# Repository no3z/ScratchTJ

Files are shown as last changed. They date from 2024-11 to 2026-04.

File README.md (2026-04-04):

# ScratchTJ MK2 -- DIY Digital Scratch Turntable

A fully open-source portable scratch instrument built around a Raspberry Pi, Arduino Nano, and the [xwax](http://www.xwax.co.uk/) digital vinyl emulation engine.

This project is based on the work by **[the_rasteri](https://github.com/rasteri)** and the [SC1000](https://github.com/rasteri/SC1000) open-source portable turntable. The software is a fork of the SC1000 codebase, and the hardware design draws heavily from that project. Without rasteri's original work, ScratchTJ would not exist.

> **Project status:** this repository tracks **MK2**.
> The previous generation is preserved in Git tag **`mk1`**.

**[Full Build Guide](docs/BUILD_GUIDE.md)** -- step-by-step wiring, assembly, and component documentation.

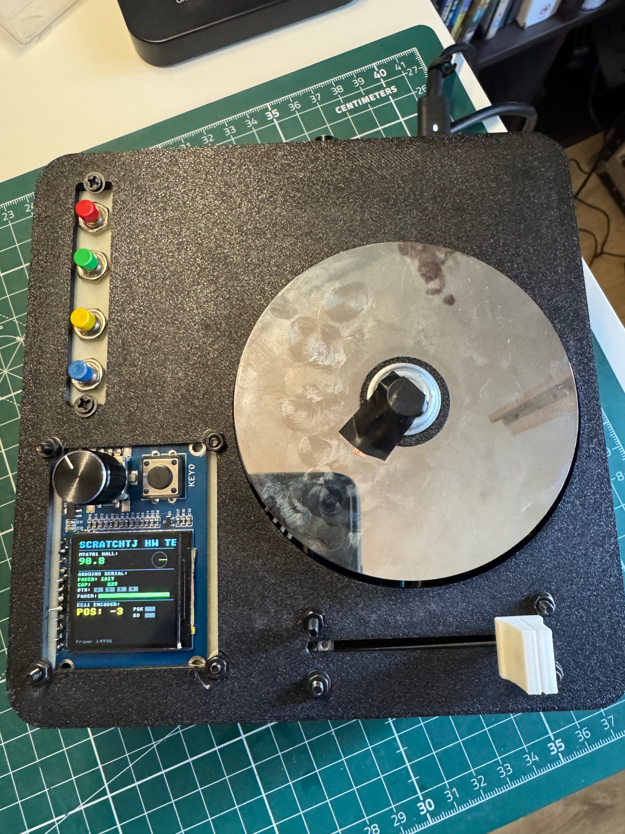
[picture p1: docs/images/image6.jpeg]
MK2 top view -- platter, TFT display, buttons, and fader


▶ *Click to play video:*

Scratch demo (https://youtu.be/LH9r2fsUk-c?si=Gcfz0AI6pA22WaxF)

## Features

- Two independent decks: beats + scratch sample, mixed through a DJ fader
- MT6701 magnetic angle sensor for high-precision platter tracking (MK2 upgrade from 600 PPR optical)
- ST7789 240x240 TFT display with rotary encoder menu navigation
- Touch-sensitive HDD platter with capacitive sensing
- Four cue buttons via Arduino (A0--A3) with short-press jump and long-press set
- Two function modes for cue buttons: **CUE** (jump/set cue points) and **SETTINGS** (platter-based parameter control)
- SETTINGS mode: hold button + rotate platter to adjust pitch, platterspeed, volume (gain), or toggle start/stop
- Active deck switching via rotary long press -- platter, cue buttons, and display follow selected deck
- Live input recording from AudioInjector capture
- Save/load configuration via Config menu
- Binary serial protocol at 500 kbaud between Arduino and Pi
- All key parameters tunable in real time from the menu or SETTINGS function buttons

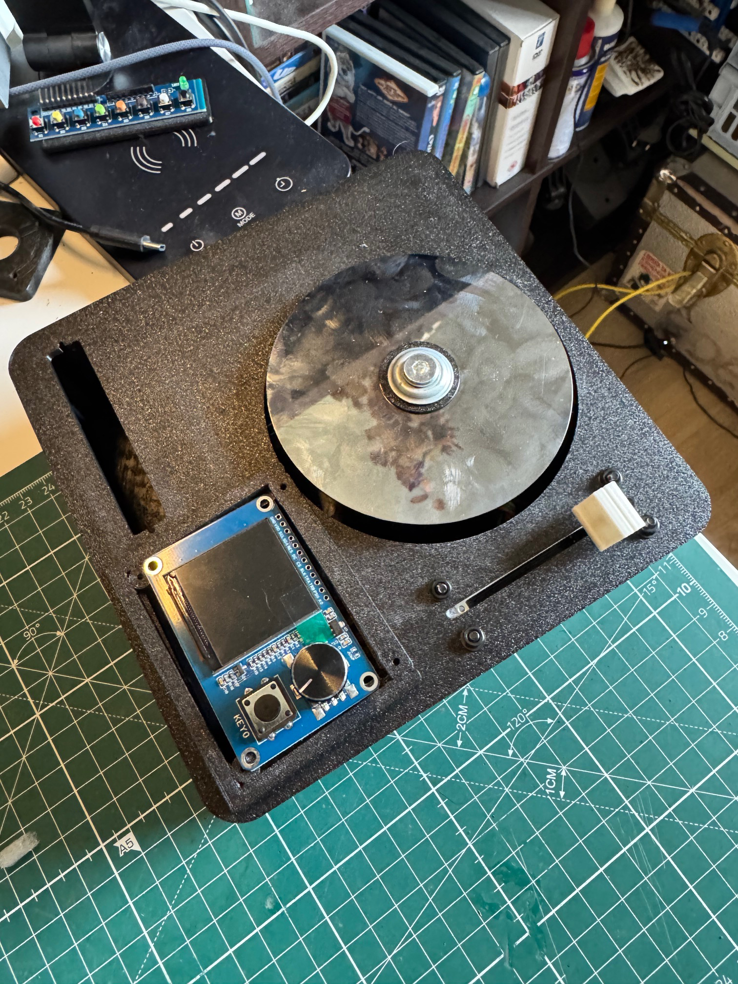
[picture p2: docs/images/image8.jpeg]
MK2 alternate angle -- TFT and platter closeup


▶ *Click to play video:*

Randomize function scratch (https://youtu.be/6zyM5B6j0_E?si=wSV1pAbMLMZF-k79)

## Architecture

```
+--------------+   Serial 500kbaud   +--------------+   I2S Audio   +-----------------+
| Arduino Nano | ------------------- | Raspberry Pi | ------------ | AudioInjector   |
|              |   7-byte binary pkt |              |              | Sound Card      |
| - Fader      |   (sync+data+XOR)   | - xwax       |              +-----------------+
| - Cap sensor |                     | - TFT menu   |
| - 4 cue btns |                     |              |
+--------------+                     | - MT6701 I2C |
                                     | - Recording  |
                                     +--------------+
```

The Arduino handles the DJ crossfader, capacitive touch sensor, and 4 cue buttons, sending data as 7-byte binary packets with XOR checksum at ~500 Hz. The Raspberry Pi reads the MT6701 magnetic encoder via I2C, runs the audio engine, TFT menu system, and live recording.

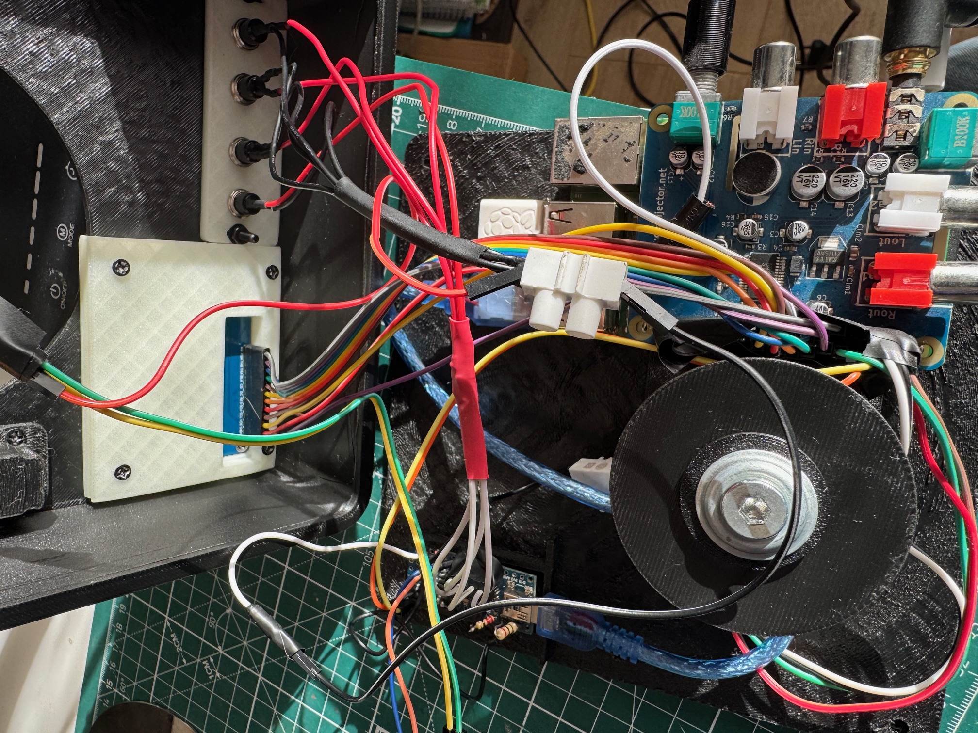
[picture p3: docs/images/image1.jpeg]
MK2 internals -- wiring, platter mount, and AudioInjector sound card


## Bill of Materials

- **Raspberry Pi** (2/3/4)
- **AudioInjector Sound Card** (I2S audio HAT)
- **Arduino Nano** (serial at 500 kbaud for fader + cap touch)
- **MT6701 Magnetic Angle Sensor** (I2C, platter position)
- **ST7789 240x240 TFT Display** (SPI, menu UI)
- **Rotary Encoder with Push Button** (menu navigation)
- **60mm DJ Crossfader**
- **HDD Platter** (capacitive touch surface)
- **Cue Buttons** (4x, wired to Arduino A0--A3)
- **Diametric Magnet** (for MT6701 sensing)
- **3D Printed MK2 Enclosure**

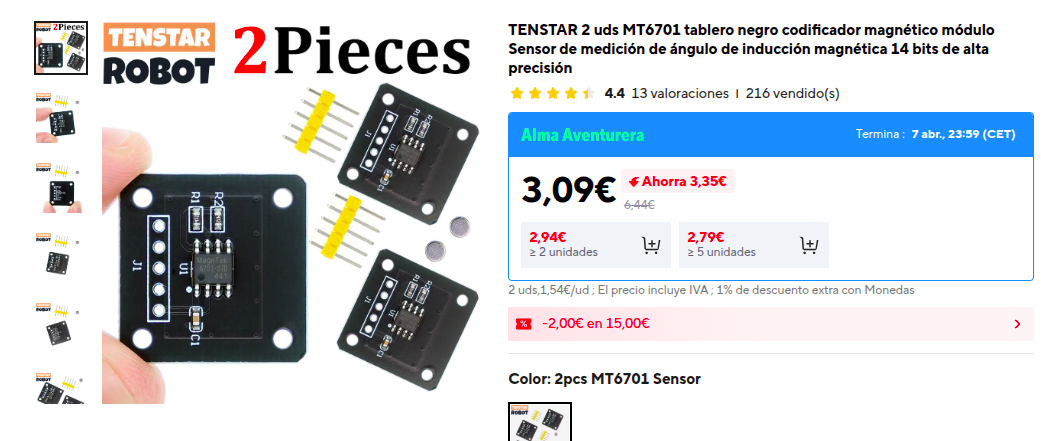
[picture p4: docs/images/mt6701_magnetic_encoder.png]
MT6701 magnetic encoder module

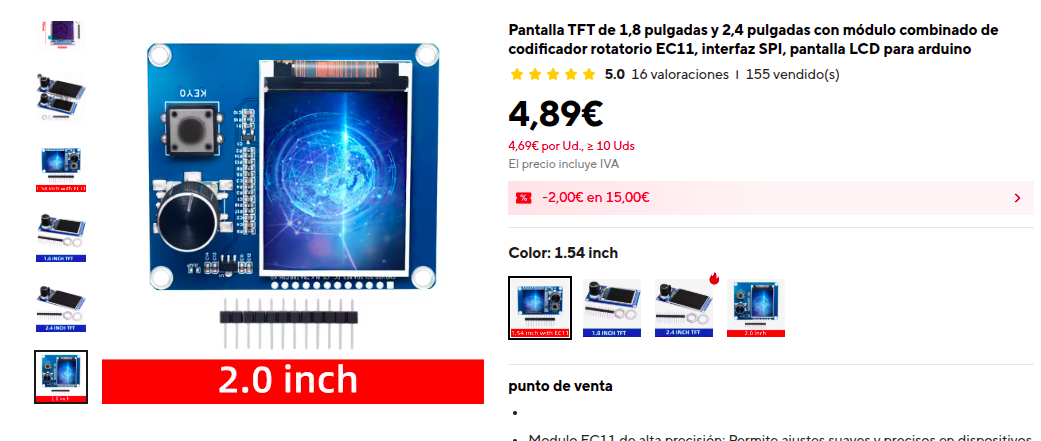
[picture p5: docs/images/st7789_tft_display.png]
ST7789 TFT display module


## Software Overview

Key source files:

| File | Purpose |
|---|---|
| `arduino_nano/arduino_nano.ino` | Arduino firmware: fader, cap sensor, cue buttons, binary serial |
| `software/sc_input.c` | Serial reader, MT6701 I2C encoder, platter-to-audio position mapping |
| `software/player.c` | Audio engine with cubic interpolation, pitch filtering, slipmat simulation |
| `software/xwax.c` | Main application, deck init, shared variable registration |
| `software/recording.c` | Live input recording from ALSA capture devices |
| `software/cues.c` | Cue point system with per-track save/load |
| `software/lcd_menu.c` | TFT display, rotary encoder menu navigation |
| `software/deck_menu.c` | Per-deck menu: file browse, transport, cue screen, recording |
| `software/controller_menu.c` | Config menu: Sound Settings, Global Settings, Info |
| `software/preset_menu.c` | 3-slot preset save/load (compiled, not yet wired into menu) |
| `software/shared_variables.c` | Thread-safe runtime variable system for menu-tunable parameters |

## Menu System

The menu is driven by the EC11 rotary encoder (scroll + push) and the KB0 button (GPIO 17). The home screen shows a live platter visualization for the active deck with info column, fader graph, and cue indicators. A function mode info strip shows the current button assignments.

▶ *Click to play video:*

Menu and buttons demo (https://youtube.com/shorts/j2CSrozANF8?si=jhMayBKkclHSwKNa)

### Full Menu Tree

```
HOME SCREEN
│  Active deck platter visualization (fader arc, ghost/physical needles,
│  touch glow, elapsed time), speed/pitch/motor/slip info column,
│  fader history graph, progress bar, other deck compact strip,
│  function mode info strip, cue flash banner, cue bar overlay
│  Title bar shows [S] indicator when in SETTINGS mode
│  Long press rotary = switch active deck (DECK 1 ↔ DECK 2)
│  KB0 or encoder turn → Main Menu
│
├── Dk2 [▶/■] filename 0:00  .. Deck 2
│   ├── Load File
│   │   ├── Start/Stop
│   │   ├── Next File
│   │   ├── Previous File
│   │   ├── Random File
│   │   ├── Next Folder
│   │   ├── Previous Folder
│   │   └── Record ............ enter recording workflow
│   │   (KB0 enters folder/file browser for the selected action)
│   ├── Start/Stop ............. toggle playback
│   ├── Settings
│   │   ├── Jog Pitch Mode ..... toggle pitch bend via platter
│   │   ├── Toggle Jog Reverse . reverse platter direction
│   │   └── Platter Speed ...... adjust encoder-to-audio ratio
│   └── Info ................... filename, path, position, pitch,
│                                volume, touch state, motor speed, cue points
│
├── Dk1 [▶/■] filename 0:00  .. Deck 1 (same structure as Deck 2)
│
├── Randomize .................. load random tracks on both decks
│
├── Record Dk2 ................. recording workflow
│   ├── Record Setup
│   │   ├── Source .............. AudioInjector hw:1,0 (KB0 cycles)
│   │   └── RECORD ............. KB0 starts capture
│   └── Recording .............. live MM:SS timer, blinking red dot
│                                KB0 = stop (auto-loads into deck)
│
├── Btn: CUE/SETTINGS ......... toggle function mode for cue buttons
│
├── Config
│   ├── Sound Settings ......... all ALSA mixer controls
│   │   └── (per control) ...... volume slider, boolean, or enum
│   ├── Global Settings ........ all registered shared variables
│   │   └── (per variable) ..... value adjust with min/max/step
│   │       (fader variables show live curve graph)
│   ├── Save Config ............ writes to ~/.scratchtj/config.cfg
│   └── Reset Defaults ......... restores all to factory values
│
└── Info
    ├── CPU/Mem ................ live CPU and memory usage
    └── Version ................ "ScratchTJ v2" + build date
```

### Navigation Controls

| Control | Action |
|---|---|
| Encoder rotate | Scroll through menu items / adjust values |
| KB0 button (GPIO 17) | Select / confirm / enter submenu |
| Encoder push (GPIO 27) short press | Back / cancel / return to previous menu |
| Encoder push long press (500ms) | Switch active deck (DECK 1 ↔ DECK 2) |

### Function Modes (CUE / SETTINGS)

Toggle via main menu item "Btn: CUE/SETTINGS". Default is SETTINGS on startup.

**CUE mode** -- cue buttons work as cue points:

| Button | Action |
|---|---|
| Short press | Jump to stored cue point |
| Long press (1s) | Set cue point at current position |

**SETTINGS mode** -- cue buttons become parameter controls:

| Button | Color | Function | Control |
|---|---|---|---|
| Btn 1 | Red | Pitch (note_pitch) | Hold + rotate platter (0.25x -- 4.0x) |
| Btn 2 | Green | Platter Speed | Hold + rotate platter |
| Btn 3 | Yellow | Start/Stop | Press to toggle |
| Btn 4 | Blue | Volume (gain) | Hold + rotate platter (up to x3.60) |

When holding a SETTINGS button and rotating the platter, a live overlay shows the parameter name, value, and gauge bar. Audio position is frozen during adjustment. Config auto-saves when buttons are released.

### Runtime-Tunable Parameters

All adjustable live from Config > Global Settings:

| Parameter | Default | Range | Step | Description |
|---|---|---|---|---|
| Fad Factor | 0.1 | 0.01 - 10 | 0.01 | Fader curve transition point |
| Fad Power | 0.2 | 0.01 - 10 | 0.01 | Fader curve exponent |
| Fad Switch | 1.0 | 0 - 1 | 1.0 | Fader direction (0=normal, 1=reversed) |
| slippiness | 200 | 1 - 3000 | 25 | Slipmat simulation feel |
| target_pitch | 40 | 1 - 240 | 1 | Position tracking gain |
| brakespeed | 3000 | 1 - 10000 | 500 | Stop button deceleration rate |
| platterspeed | 9100 | 1 - 32768 | 256 | Encoder-to-audio position ratio |
| blipthreshold | 400 | 50 - 2048 | 50 | Encoder glitch rejection threshold |
| pitch_filter | 0.1 | 0.01 - 1.0 | 0.01 | Pitch low-pass filter (0=smooth, 1=instant) |
| fader_sharp | 1.0 | 0 - 1.0 | 0.05 | Fader sharpness |
| fhist_secs | 2.0 | 0.1 - 120 | 0.1 | Fader history graph time window (seconds) |

### Serial Protocol

```
Byte:  [0]     [1]     [2]     [3]     [4]     [5]       [6]
       SYNC    fHi     fLo     capHi   capLo   buttons   XOR
       0xAA    ──fader──       ──cap touch──    4-bit     checksum
               (10-bit)        (16-bit)         bitfield  (bytes 1-5)
```

In MK2, the Arduino no longer sends encoder angle data -- the Pi reads the MT6701 directly over I2C. The packet is 7 bytes: sync, fader (2), cap touch (2), cue buttons (1), checksum (1).

Handshake: Pi sends `0x53` ('S'), Arduino replies `'T'`. Watchdog detects 2-second timeouts with DTR hard-reset after 3 consecutive failures.

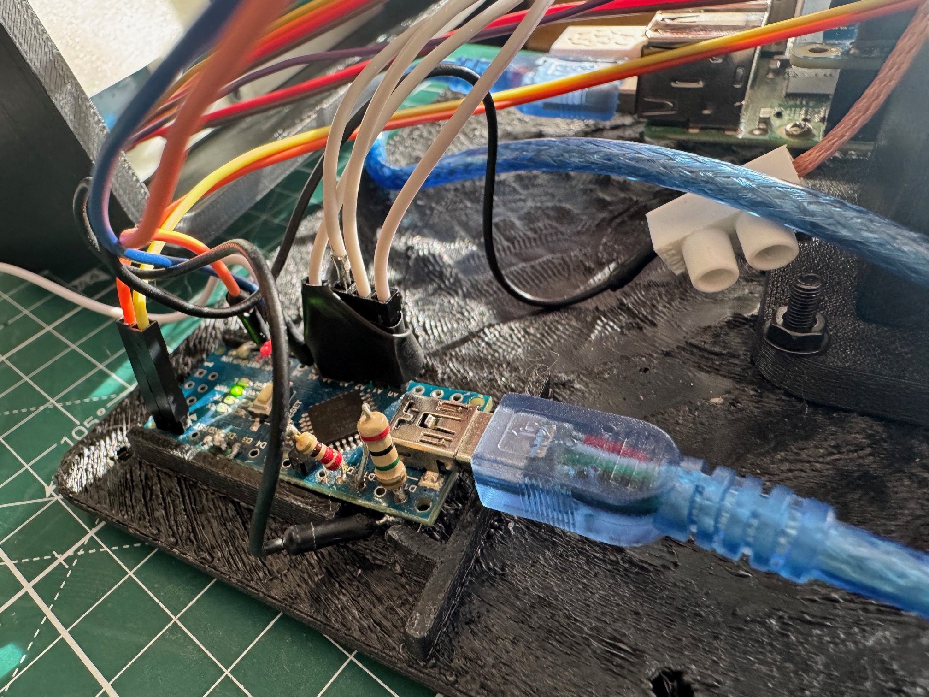
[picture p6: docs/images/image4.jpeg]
Arduino Nano in its 3D printed cradle -- the 1.2kΩ resistor and the wire going to the platter spring contact are both soldered to the same D12 sense pin


## Building

### Prerequisites (on the Raspberry Pi)

- GCC, make
- SDL2 development libraries
- ALSA development libraries
- wiringPi

### Compile and Run

```bash
cd ~/ScratchTJ/software
make -j4
sudo LC_ALL=en_GB.utf8 nice -n -19 ./xwax
```

If locale is not set as above, xwax may fail to start correctly.

### Flash the Arduino

Open `arduino_nano/arduino_nano.ino` in the Arduino IDE. Install the `CapacitiveSensor` library, select Arduino Nano, and upload. Both the Arduino firmware and the Pi software must be updated together since they share the binary serial protocol.

Audio samples go in `~/samples/` (scratch deck) and `~/beats/` (beat deck). The paths are configured in `xwax.c`.

▶ *Click to play video:*

Little scratch demo (https://youtube.com/shorts/L9gylG18938?si=5t2caiyyweBquCjl)

## Hardware Test Scripts

Hardware test and diagnostic scripts are in the [`hw_test/`](hw_test/) directory.

## Documentation

- **[Build Guide](docs/BUILD_GUIDE.md)** -- Step-by-step wiring and assembly
- **[Installation](docs/INSTALLATION.md)** -- Software installation details
- **[Software Architecture](docs/SOFTWARE.md)** -- Thread model, subsystems
- **[Enclosure Design](docs/enclosure/ENCLOSURE_DESIGN.md)** -- 3D printable parts
- **[Parametric Encoder Mount](docs/enclosure/parametric_encoder_mount.scad)** -- OpenSCAD source for the MT6701 encoder mount (fully parametric)

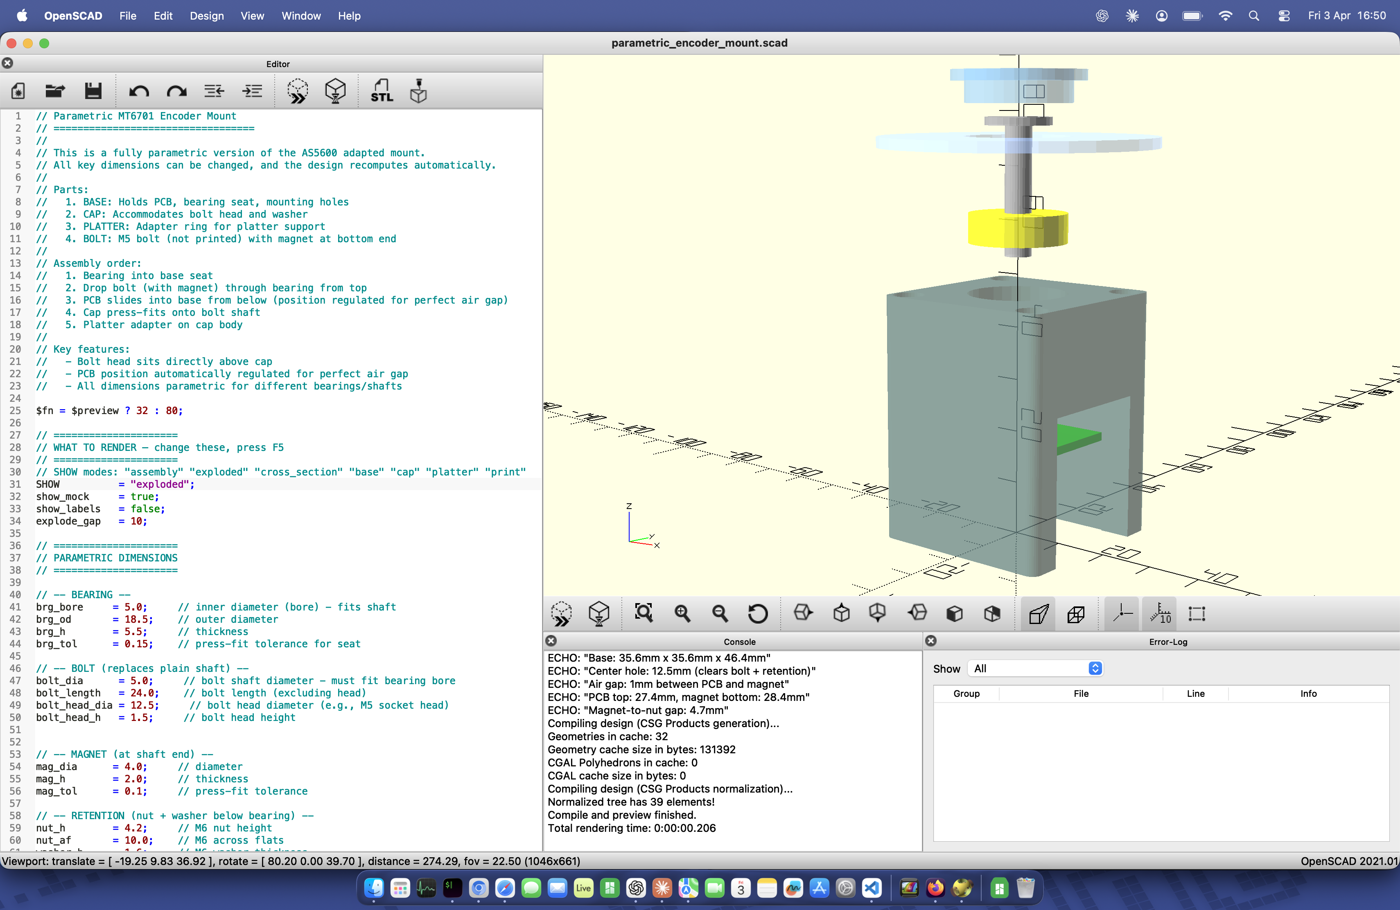
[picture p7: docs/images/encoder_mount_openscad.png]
Encoder mount exploded view in OpenSCAD


## Project History

ScratchTJ started as an adaptation of rasteri's SC1000 to run on a Raspberry Pi with an AudioInjector audio hat, replacing the Olimex A13 and custom PCB with off-the-shelf components (Arduino Nano, standard encoder, DJ fader) and serial communication instead of I2C/SPI.

MK2 replaces the 600 PPR optical encoder with an MT6701 magnetic angle sensor, the 1602A LCD with an ST7789 TFT display, and introduces a redesigned enclosure with better platter support and Hall-sensor alignment.

## License and Attributions

Licensed under GNU GPL v2.

- **[xwax](http://www.xwax.co.uk/)** by Mark Hills -- the digital vinyl emulation engine at the core of this project
- **[SC1000](https://github.com/rasteri/SC1000)** by the_rasteri -- the open-source portable turntable that ScratchTJ is forked from
- **[AudioInjector](http://www.audioinjector.net/)** -- I2S sound card HAT for Raspberry Pi

---

Kiitos paljon ja happy scratching!

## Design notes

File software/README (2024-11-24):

Rebutchered the butchered repository: 
SC1000 Xwax - xwax butchered to work with the SC1000 digital scratch instrument

Added LCD menus, and input interfaces via arduino nano sending data trought serial to rpi

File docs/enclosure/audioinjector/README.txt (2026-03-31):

AudioInjector Case by dj_doughy on Thingiverse: https://www.thingiverse.com/thing:5854768

Summary:
This object was made in Tinkercad. Edit it online https://www.tinkercad.com/things/gVtFypLfkFGThis case was designed for my DIY Eyesy Visual Synth project. More info can be found over at https://blog.djdoughy.com/2022/08/raspberry-pi-4-eyesy-clone-guide.htmlThe case was designed for a RasPi 4, but I believe the openings are big enough to work for a 3B.

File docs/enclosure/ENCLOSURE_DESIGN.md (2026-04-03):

# ScratchTJ v2.0 — Enclosure Design Document

## Overview

Complete redesign of the ScratchTJ DJ controller enclosure, replacing the single-piece Tinkercad box with a modular, parametric OpenSCAD design optimized for the MT6701 magnetic encoder upgrade.

### Key Changes from v1

| Feature | v1 (Current) | v2 (New) |
|---|---|---|
| Enclosure | Single box (Tinkercad) | 2-part: base + top plate |
| Encoder | 600 PPR optical rotary | MT6701 magnetic (14-bit, I2C) |
| Bearing | None (encoder shaft) | 625 bearing (5mm/16mm/5mm) |
| Display | 1602A LCD (I2C 0x27) | SSD1306 0.96" OLED (I2C 0x3C) |
| Touch sensing | Wire through encoder shaft | Slip ring + spring contact |
| Controls | Front panel (LCD sideways) | Top surface (DJ deck style) |
| Design tool | Tinkercad | OpenSCAD (parametric) |

---

## Architecture

### Two-Part Stack

```
        ┌─────────────────────────────────────────────────────┐
        │              TOP PLATE (Part B)                      │
        │  ┌────────┐     ┌─────────────────────────────┐    │
        │  │  OLED  │     │      PLATTER OPENING        │    │
        │  │ (up)   │     │       (always exposed)      │    │
        │  └────────┘     │                             │    │
        │  (ENC)          │         HDD disc            │    │
        │  [A] [B]        │        spins here           │    │
        │                 └─────────────────────────────┘    │
        │  ═══════════ FADER ═══════════                     │
        ├─CLIPS──────────────────────────────────────CLIPS───┤
        │            ELECTRONICS BASE (Part A)                │
        │                                                     │
        │  ┌──────────────────────┐   ┌─────────────────┐   │
        │  │  Raspberry Pi 2/3    │   │  MT6701 sensor  │   │
        │  │  + AudioInjector HAT │   │  on pedestal    │   │
        │  │                      │   │  + 625 bearing  │   │
        │  └──────────────────────┘   │  + rotor hub    │   │
        │  ┌───────────┐              └─────────────────┘   │
        │  │Arduino Nano│                                    │
        │  └───────────┘                                     │
        └─────────────────────────────────────────────────────┘
```

### Top Plate Layout (DJ Deck Style)

All controls face UP for natural DJ interaction:

```
     ┌──────────────────────────────────────────────┐
     │                                               │
     │  ┌────────┐      ┌───────────────────────┐   │
     │  │  OLED  │      │                       │   │
     │  │ 0.96"  │      │                       │   │
     │  └────────┘      │    HDD PLATTER        │   │
     │                   │     Ø95mm             │   │
     │  (🔘 ENC)        │   always exposed      │   │
     │  menu knob        │   touch to scratch    │   │
     │                   │                       │   │
     │  [🔴] [🔵]      │                       │   │
     │  Enter  Back      └───────────────────────┘   │
     │                                               │
     │  ══════════════════════════════════════════   │
     │          60mm CROSSFADER                      │
     │                                               │
     └──────────────────────────────────────────────┘
       FRONT
```

---

## Printable Parts (7 total)

### Part A: Electronics Base — `v2_base.scad`

The main enclosure box. Open top, all electronics mount inside.

- **Dimensions:** ~145mm x 175mm x 60mm (outer) — matches v1 footprint
- Pi standoffs (4x M2.5, 6mm height)
- Arduino Nano friction-fit cradle
- MT6701 sensor pedestal with bearing seat (rises from floor to correct height)
- Fader mounting rails
- 6x clip receivers on inner walls
- Back panel: 4x 3.5mm audio jack holes, micro-USB, HDMI, USB-A cutouts
- Left side: Arduino USB programming access
- Ventilation slots on both sides

### Part B: Top Plate — `v2_top_plate.scad`

DJ deck surface. Clips onto base rim.

- **Thickness:** 4mm (structural)
- Platter opening (Ø100mm) with raised cosmetic surround — fits 95mm HDD platter
- OLED window with bezel (screen faces up)
- OLED PCB pocket (recessed from below)
- EC11 encoder hole with raised ring surround
- 2x button holes with surrounds
- Fader slot (66mm x 4mm)
- 6x clip hooks (snap onto base receivers)
- Cable pass-through slot near platter

### Rotor Hub — `v2_rotor_hub.scad`

The spinning part. Press-fits onto 625 bearing inner race.

- **Dimensions:** Ø26mm body, Ø32mm flange, 12mm tall
- Bottom: 6x2.5mm magnet pocket (press-fit)
- Middle: Slip ring groove (3mm wide, 0.8mm deep for copper tape)
- Wire channel from ring to flange (for platter connection)
- Top: Platter flange with 3x M2 mounting holes
- Radial M2.5 set screw hole
- **Print: 4 walls, 80% infill, 0.16mm layers**

### Fixed Shaft — `v2_shaft.scad`

Stationary shaft through the bearing center.

- Ø4.8mm shaft (clearance fit in 5mm bore)
- Base flange Ø9mm
- M3 through-bolt for securing to pedestal
- Countersink on top for bolt head
- **Print: 100% infill**

### Spring Contact Holder — `v2_spring_holder.scad`

Holds the brass spring strip that presses against the slip ring.

- Slot for 4mm wide spring strip
- Chamfered entry for easy spring insertion
- M2 clamping screw hole (presses spring down)
- Wire hole in bottom (solder connection to Arduino D12)
- Mounting tab with M3 hole (attaches to sensor pedestal)

### Platter Adapter Ring — `v2_platter_adapter.scad`

Optional ring to center the HDD platter on the hub flange.

- Recess for Ø95mm platter
- Center hole clears hub flange
- Weight reduction cutouts

### Legacy reference: `mt6701_mount.scad`

Earlier standalone MT6701 mount design. Superseded by the integrated pedestal in `v2_base.scad`, kept for reference.

---

## Slip Ring System (Capacitive Touch)

### Problem

The v1 design routes a copper wire through the optical encoder shaft to make electrical contact with the HDD platter. With the MT6701 magnetic encoder (contactless), there is no mechanical shaft connection to the platter.

### Solution: Rotating Slip Ring + Fixed Spring Contact

```
    Arduino D12 (sense) ──wire──┐
                                │
                        ╔═══════╧═══════╗
                        ║ SPRING CONTACT ║  (fixed, brass strip)
                        ║   presses on   ║
                        ╚═══════╤═══════╝
                                │ physical contact
                        ╔═══════╧═══════╗
                        ║  COPPER RING   ║  (rotates with hub)
                        ║  in hub groove ║
                        ╚═══════╤═══════╝
                                │ soldered wire
                        ╔═══════╧═══════╗
                        ║  HDD PLATTER   ║  (metal, user touches)
                        ╚═══════════════╝
                                │
                           User's finger
                         (body capacitance)
```

### Circuit

The existing Arduino capacitive sensing circuit is **unchanged**:

```
Arduino D10 ──── 1.2kΩ ──── Arduino D12 ──── wire ──── spring contact
                                                              │
                                                        copper ring
                                                              │
                                                        HDD platter
```

The `CapacitiveSensor` library measures charge time through the 1.2kΩ resistor. When a finger touches the platter, body capacitance increases the charge time, and the reading goes up.

### Materials for Slip Ring

| Item | Specification | Source |
|---|---|---|
| Copper tape | 3mm wide, adhesive back | AliExpress / electronics store |
| Spring strip | Phosphor bronze, 0.1-0.2mm thick, 3mm wide | Cut from shim stock |
| Wire | 26-30 AWG silicone | Standard hookup wire |

### Assembly

1. Wrap copper tape into the rotor hub groove (full ring, overlapping ends)
2. Solder a wire from the copper ring through the hub wire channel to the platter contact point on the flange
3. Bend the brass spring strip — one end curved (contact tip), other end flat (solder pad)
4. Insert spring into holder slot, curved tip pointing toward hub
5. Secure with M2 screw through clamping hole
6. Solder wire from spring flat end to Arduino D12

---

## Wiring Changes (v1 → v2)

### Removed

- 1602A LCD display (I2C address 0x27)
- 600 PPR optical rotary encoder (Arduino D2/D3 interrupts)
- Encoder shaft wire for capacitive touch

### Added

- SSD1306 0.96" OLED (I2C address 0x3C, same SDA/SCL pins)
- MT6701 magnetic encoder (I2C address 0x06, same I2C bus, read directly by Pi)
- Slip ring system (replaces shaft wire, same D10/D12 circuit)

### Modified Arduino Protocol

The Arduino no longer reads the platter encoder. The serial packet shrinks:

| v1 Packet (8 bytes) | v2 Packet (6 bytes) |
|---|---|
| `0xAA` sync | `0xAA` sync |
| Fader high | Fader high |
| Fader low | Fader low |
| ~~Angle high~~ | Cap high |
| ~~Angle low~~ | Cap low |
| Cap high | Checksum (XOR 1-4) |
| Cap low | |
| Checksum | |

The Pi reads the MT6701 angle directly over I2C at address 0x06 (14-bit, register 0x03-0x04).

### I2C Bus Map

| Address | Device | Notes |
|---|---|---|
| 0x06 | MT6701 | 14-bit angle, read by Pi at ~1kHz |
| 0x3C | SSD1306 OLED | 128x64 pixels, menu display |

---

## Dimensions Summary

| Parameter | V1 (OBJ measured) | V2 (Design) |
|---|---|---|
| Outer width | 140mm | 145mm |
| Outer depth | 176mm | 175mm |
| Base height | 62mm | 60mm |
| Top plate | N/A (open) | 4mm |
| Total height | 70mm (incl. LCD bracket) | 64mm + hub + platter |
| Platter bay | 120x120mm square | Ø100mm circle |
| Fader slot | 60x9mm | 60x4mm |
| Wall thickness | ~2.5mm | 2.5mm |
| Corner radius | ~5mm | 5mm |

---

## Print Settings

| Part | Material | Layer | Walls | Infill | Supports |
|---|---|---|---|---|---|
| Base | PETG | 0.2mm | 3 | 20% | Yes (back panel cutouts) |
| Top plate | PETG | 0.2mm | 3 | 20% | Yes (clip hooks) |
| Rotor hub | PETG | 0.16mm | 4 | 80% | No |
| Shaft | PETG | 0.16mm | 4 | 100% | No |
| Spring holder | PETG | 0.16mm | 3 | 40% | No |
| Platter adapter | PLA/PETG | 0.2mm | 2 | 15% | No |

---

## Legacy Files (v1 Reference)

v1 Tinkercad files (`djsc.obj`, `tinker.obj`) have been removed. They are available in the Git history under the `mk1` tag if needed.

---

## Next Steps

1. **Open `v2_assembly.scad` in OpenSCAD** — verify layout, adjust parameters
2. **Measure your actual components with calipers** — update `v2_common.scad`
3. **Print the rotor hub first** — test bearing fit and slip ring groove
4. **Modify `sc_input.c`** — add I2C MT6701 reading, update serial protocol
5. **Modify `lcd_menu.c`** — replace 1602 LCD driver with SSD1306 OLED driver
6. **Update Arduino firmware** — remove encoder reading, simplify packet to 6 bytes

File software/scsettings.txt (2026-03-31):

#######################
# SC1000 config file #
######################
# Any lines beginning with # are ignored

###################
# General Options #
###################
#
# Fader thresholds for hysteresis
# You might need to adjust these for different faders
# faderopenpoint should always be 
# more than faderclosepoint

buffersize=256

# Value required to open the fader when it's closed
faderopenpoint=5

# Value required to close the fader when it's opened
faderclosepoint=3

# 0 to disable platter, default 1 (enabled)
platterenabled=1

# Ratio of platter movement to sample movement
# For 14-bit MT6701 (CPR=16384):
#   16384 = 1 second for every platter rotation
#   12288 = equivalent to 45rpm record
#   9100  = equivalent to 33rpm (default)
# For original SC1000 12-bit (CPR=4096): multiply above by 0.25
platterspeed=9100

# How long the stop button takes to stop the track
# Higher is longer, default = 3000
brakespeed=3000

# Pitch range % of pitch bend MIDI command, default 50%
pitchrange=50

# How long to delay before looking for MIDI devices
# Useful if your MIDI device takes a long time to initialize
# Or to give you time to switch your phone to MIDI mode
mididelay=5

# Set this to 1 or 2 to make the fader cut the beats
# 1 will cut on the left, 2 will cut on the right
cutbeats=0

####################
#   GPIO Mapping   #
####################
#
# This section is used to wire up buttons.
# These can be either directly wired to the Olimex module,
# or on an external MCP23017 GPIO expander
# Format is : 
# gpio=port,pin,pull,edge,action

# port is 0 for MCP23017, or 123456 for ports BCDEFG of A13 on Olimex
# pin number- for MCP23017, A0-A7 is 0-7 and B0-B7 is 8-15
# pull is 1 for pullup, 2 for pulldown
# edge is 1 for pressing edge, 2 for holding action, 3 for pressed while shifted, 4 for held while shifted, 0 for releasing edge
# action is one of :
# 
# (replace x with 0 for beats or 1 for samples) :
# CHx_CUE - Set and trigger cue points
# CHx_SHIFTON - Activate shift mode (ignores x)
# CHx_SHIFTOFF - Deactivate shift mode (also ignores x)
# CHx_STARTSTOP - Start or Stop the track
# CHx_NOTEy - Change the pitch musically, replace y with the note number (60 being 0%)
# CHx_GND - make the pin an output and set it low - used to provide additional ground connections (ignores x)
# gpio=port,pin,pull,edge,action

#### SC500 Buttons ####
# Detection pin
gpio=6,11,1,1,CH0_SC500

# Shift
gpio=2,9,1,1,CH0_SHIFTON
gpio=2,9,1,0,CH0_SHIFTOFF

# Beat Transport
gpio=2,14,1,1,CH0_PREVFILE
gpio=2,14,1,2,CH0_PREVFOLDER
gpio=2,14,1,3,CH0_RANDOMFILE

gpio=2,13,1,1,CH0_STARTSTOP

# even though this is on a beat button it still affects sample
gpio=2,13,1,3,CH1_JOGREVERSE

gpio=2,10,1,1,CH0_NEXTFILE
gpio=2,10,1,2,CH0_NEXTFOLDER
gpio=2,10,1,3,CH0_JOGPIT
gpio=2,10,1,0,CH0_JOGPSTOP

# Beat Volume Buttons
gpio=4,5,1,1,CH0_VOLUP
gpio=4,5,1,2,CH0_VOLUHOLD
gpio=4,4,1,1,CH0_VOLDOWN
gpio=4,4,1,2,CH0_VOLDHOLD

# Sample Transport
gpio=2,5,1,1,CH1_PREVFILE
gpio=2,5,1,2,CH1_PREVFOLDER
gpio=2,5,1,3,CH1_JOGPIT
gpio=2,5,1,0,CH1_JOGPSTOP

gpio=2,6,1,1,CH1_STARTSTOP
gpio=2,6,1,3,CH1_RECORD

gpio=2,8,1,1,CH1_NEXTFILE
gpio=2,8,1,2,CH1_NEXTFOLDER
gpio=2,8,1,3,CH1_RANDOMFILE

# Sample volume buttons
gpio=1,10,1,1,CH1_VOLUP
gpio=1,10,1,2,CH1_VOLUHOLD
gpio=1,4,1,1,CH1_VOLDOWN
gpio=1,4,1,2,CH1_VOLDHOLD

# Sample cue buttons
gpio=2,4,1,1,CH1_CUE
gpio=2,4,1,3,CH1_DELETECUE
gpio=2,7,1,1,CH1_CUE
gpio=2,7,1,3,CH1_DELETECUE
gpio=2,11,1,1,CH1_CUE
gpio=2,11,1,3,CH1_DELETECUE
gpio=2,12,1,1,CH1_CUE
gpio=2,12,1,3,CH1_DELETECUE

#### Expansion port J7 ####
gpio=6,10,1,1,CH0_SHIFTON
gpio=6,10,1,0,CH0_SHIFTOFF
gpio=1,15,1,1,CH0_STARTSTOP
gpio=1,16,1,1,CH1_STARTSTOP

gpio=2,3,1,1,CH1_CUE
gpio=2,0,1,1,CH1_CUE
gpio=2,2,1,1,CH1_CUE
gpio=2,1,1,1,CH1_CUE

gpio=2,3,1,3,CH1_DELETECUE
gpio=2,0,1,3,CH1_DELETECUE
gpio=2,2,1,3,CH1_DELETECUE
gpio=2,1,1,3,CH1_DELETECUE

#### MCP23017 Buttons ####
gpio=0,0,0,1,CH0_GND

gpio=0,1,1,1,CH1_CUE
gpio=0,2,1,1,CH1_CUE
gpio=0,3,1,1,CH1_CUE
gpio=0,4,1,1,CH1_CUE
gpio=0,5,1,1,CH1_CUE
gpio=0,6,1,1,CH1_CUE
gpio=0,7,1,1,CH1_CUE

gpio=0,1,1,3,CH1_DELETECUE
gpio=0,2,1,3,CH1_DELETECUE
gpio=0,3,1,3,CH1_DELETECUE
gpio=0,4,1,3,CH1_DELETECUE
gpio=0,5,1,3,CH1_DELETECUE
gpio=0,6,1,3,CH1_DELETECUE
gpio=0,7,1,3,CH1_DELETECUE

gpio=0,8,1,1,CH1_STARTSTOP
gpio=0,9,1,1,CH0_SHIFTON
gpio=0,9,1,0,CH0_SHIFTOFF 
gpio=0,10,1,1,CH1_CUE
gpio=0,10,1,3,CH1_DELETECUE
gpio=0,11,1,1,CH0_STARTSTOP
gpio=0,12,0,1,CH1_GND
gpio=0,13,1,1,CH1_CUE
gpio=0,14,1,1,CH1_CUE
gpio=0,15,1,1,CH1_CUE
gpio=0,13,1,3,CH1_DELETECUE
gpio=0,14,1,3,CH1_DELETECUE
gpio=0,15,1,3,CH1_DELETECUE

################
# MIDI Mapping #
################
#
# Format is :
# Status,channel,data,edge, action
# 
# Status can be : 
# 8 - Note OFF (will also match zero-velocity Note ON)
# 9 - Note ON
# 11 - Control Change
# 14 - Pitch Bend
#
# Channel is the MIDI channel of the incoming MIDI message
#
# Data is the note or CC number - set to "255" to bind to ALL notes of a particular channel
#
# Action can be (replace x with 0 for beats or 1 for samples) :
# CHx_CUE - Set and trigger cue points
# CHx_SHIFTON - Activate shift mode (ignores x)
# CHx_SHIFTOFF - Deactivate shift mode (also ignores x)
# CHx_STARTSTOP - Start or Stop the track
# CHx_PITCH - Change the speed of the track
# CHx_NOTEy - Change the pitch musically, replace y with the note number (60 being 0%)

#### LEMUR PRESET, normally hardcoded ####

# CC 0 of channels 0/1 is volume
midii=11,0,0,1,CH0_VOLUME
midii=11,1,0,1,CH1_VOLUME

# Pitch bend on channels 0 and 1 is pitch

midii=14,0,0,1,CH0_PITCH
midii=14,1,0,1,CH1_PITCH

# notes on channels 0 and 1 are cue points
midii=9,0,255,1,CH0_CUE
midii=9,1,255,1,CH1_CUE

# Also add the delete cue command for shift modifier
midii=9,0,255,3,CH0_DELETECUE
midii=9,1,255,3,CH1_DELETECUE

# Notes on channel 3 are C1-style notes
midii=9,3,255,1,CH1_NOTE

# Channel 4 has various other commands mapped to its notes
# Notes 0-1 = start stop
midii=9,4,0,1,CH0_STARTSTOP
midii=9,4,1,1,CH1_STARTSTOP

# Notes 2-3 = Next file
midii=9,4,2,1,CH0_NEXTFILE
midii=9,4,3,1,CH1_NEXTFILE

# Notes 4-5 = Next folder
midii=9,4,4,1,CH0_NEXTFOLDER
midii=9,4,5,1,CH1_NEXTFOLDER

# Notes 6-7 = Prev file
midii=9,4,6,1,CH0_PREVFILE
midii=9,4,7,1,CH1_PREVFILE

# Notes 8-9 = Prev folder
midii=9,4,8,1,CH0_PREVFOLDER
midii=9,4,9,1,CH1_PREVFOLDER

# Notes 10-11 = Random file
midii=9,4,10,1,CH0_RANDOMFILE
midii=9,4,11,1,CH1_RANDOMFILE

# Note 126 = record
midii=9,4,126,1,CH0_RECORD

# Note 127 = shift
midii=9,4,127,1,CH1_SHIFTON
midii=8,4,127,3,CH1_SHIFTOFF

# Status,channel,data,edge,action

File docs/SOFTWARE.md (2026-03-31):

# ScratchTJ MK2 -- Software Architecture

## Overview

ScratchTJ is built on top of [xwax](http://www.xwax.co.uk/), an open-source digital vinyl emulation system. The ScratchTJ software adds hardware input handling, a TFT display system, a menu UI, and a configuration framework to make xwax work as a standalone DJ instrument without a monitor or keyboard.

---

## Thread Model

The software runs multiple threads for real-time performance:

```
Main thread (xwax)
  |-- Audio callback (ALSA, real-time priority)
  |-- Deck threads (track decoding, file I/O)
  |
  +-- SC_Input thread (sc_input.c)
  |     Reads serial from Arduino (fader, cap touch)
  |     Reads MT6701 encoder via I2C
  |     Processes cue button GPIO
  |     Updates deck state
  |
  +-- Rotary encoder thread (lcd_menu.c)
        Polls EC11 encoder via GPIO
        Drives menu state machine
        Renders TFT display
```

All shared state between threads is protected by mutexes in the `shared_variables` system.

---

## Module Reference

### sc_input.c -- Hardware Input Handler

The central input module. Runs in its own thread started by `SC_Input_Start()`.

**Responsibilities:**
- Opens `/dev/ttyUSB0` at 500,000 baud
- Parses 6-byte Arduino packets (sync, fader, cap touch, checksum)
- Reads MT6701 angle over I2C (`/dev/i2c-1`, address 0x06)
- Converts raw angle to deck position using `platterspeed` ratio
- Processes capacitive touch (touch/release detection with threshold)
- Reads cue button states via GPIO
- Calls into xwax deck API to update fader position, platter angle, touch state

**Key globals:**
- `capIsTouched` -- current touch state
- `ADCs[4]` -- raw analog readings
- `cue_display_states[4]` -- cue point states for display

### st7789.c -- TFT Display Driver

Low-level SPI framebuffer driver for the 240x240 ST7789 display.

**Architecture:**
- Maintains a 240x240 RGB565 framebuffer in memory
- All drawing operations write to the framebuffer
- `st7789_flush()` sends the entire framebuffer over SPI in one transfer
- Uses `/dev/spidev0.0` with direct GPIO for DC and RST pins

**Drawing primitives:**
- `st7789_pixel()`, `st7789_hline()`, `st7789_vline()`
- `st7789_fill_rect()`
- `st7789_draw_char()` / `st7789_draw_string()` -- built-in 8x8 bitmap font with scaling
- Three font sizes: `FONT_SMALL` (8px), `FONT_MEDIUM` (16px), `FONT_LARGE` (24px)

### oled_display.c -- High-Level Display Layer

Provides themed, menu-aware drawing functions on top of the ST7789 driver. Despite the filename (historical from the planned SSD1306 OLED), this drives the ST7789 TFT.

**Color theme system:**
- Title bar: dark blue background, white text
- Selected item: bright blue highlight
- Values: green text
- Cue indicators: per-cue colors (red, green, yellow, blue)
- Deck accents: cyan for Deck 1, orange for Deck 2

**High-level drawing functions:**
- `oled_draw_title_bar()` -- renders a colored title bar
- `oled_draw_menu_list()` -- scrollable list with selection highlight and scrollbar
- `oled_draw_value_screen()` -- parameter editing display (name, value, range)
- `oled_draw_cue_bar()` -- colored cue point indicators with position
- `oled_draw_progress_bar()`, `oled_draw_center_fader()` -- visualization widgets
- `oled_draw_confirm()` -- yes/no confirmation dialog

### gpio_direct.c -- Direct GPIO Access

Replaces wiringPi with direct BCM2835/BCM2836 register access via `/dev/mem`. No external library dependencies.

**Functions:**
- `gpio_direct_init()` -- maps BCM GPIO registers
- `gpio_read(pin)` / `gpio_write(pin, value)`
- `gpio_set_input(pin)` / `gpio_set_output(pin)`
- `gpio_set_pullup(pin)` -- enables internal pull-up resistor
- `gpio_millis()` -- millisecond timer

Requires root privileges for `/dev/mem` access.

### lcd_menu.c -- Menu State Machine

The menu controller. Runs in a dedicated thread polling the EC11 rotary encoder.

**State machine:**
```
MENU_HOME <---> MENU_MAIN
                  |
                  +-- MENU_DECK1 --> deck sub-menus
                  +-- MENU_DECK2 --> deck sub-menus
                  +-- MENU_CONTROLLER --> controller sub-menus
                  +-- MENU_INFO
                  +-- MENU_RECORD
```

**Encoder handling:**
- Polls CLK/DT pins at ~1kHz with debouncing
- Detects rotation direction and button press/release
- KB0 button supports short press (back) and long press (home)

### main_menu.c -- Home Screen & Top Menu

**Home screen displays:**
- Current track name and artist
- Deck play/pause state with colored indicators
- Elapsed time and remaining time
- Fader position visualization
- Cue point bar (4 slots with colors)
- Touch state indicator

**Main menu items:**
- Deck 1, Deck 2, Controller, Info, Presets

### deck_menu.c -- Per-Deck Controls

Provides file browsing, playback control, volume adjustment, and recording for each deck.

**Sub-menus:**
- **Load File** -- navigate folders, select tracks, random file
- **Settings** -- jog pitch, jog reverse
- **Volume** -- real-time volume adjustment with visual feedback
- **Info** -- track metadata display
- **Record** -- select input source and record to WAV

### controller_menu.c -- System Configuration

**Sub-menus:**
- **Sound Settings** -- ALSA mixer parameters (volume, gain, etc.)
- **Global Settings** -- all registered shared variables with real-time editing
- **Save Config** -- persist current settings to file
- **Reset Defaults** -- restore factory defaults

### preset_menu.c -- Preset System

3-slot save/load system for entire configurations.

- Each slot saves all shared variable values to `preset_N.cfg`
- Last-used preset number is stored and auto-loaded on startup
- Menu shows slot status (empty/saved) and allows save/load operations

### shared_variables.c -- Configuration Registry

Thread-safe registry of runtime-adjustable parameters.

**Features:**
- Variables registered with name, pointer, min/max, step size, default
- Mutex-protected read/write access
- Serialize to/from file (key=value format)
- Bulk reset to defaults
- Used by the menu system for real-time parameter editing

---

## Build System

The Makefile builds a single `xwax` binary:

```bash
make -j4        # Build main binary
make test_tft_ui  # Build standalone TFT test
make clean      # Remove build artifacts
```

**Dependencies:**
- GCC
- SDL2 (`libsdl2-dev`)
- ALSA (`libasound2-dev`)
- pthreads
- Math library (`-lm`)

No wiringPi, no Python, no Node.js. The entire system is pure C with standard Linux APIs.

---

## Data Flow

```
                    Arduino Nano
                   /dev/ttyUSB0
                   500,000 baud
                        |
                    [6-byte packet]
                    fader + cap touch
                        |
                        v
    MT6701 ----I2C----> sc_input.c -----> deck API (xwax)
    (angle)             |                      |
                        |                      v
                   cue buttons           Audio Engine
                   (GPIO)               (ALSA callback)
                        |                      |
                        v                      v
                   lcd_menu.c            Speaker/Headphones
                        |
                        v
                   oled_display.c
                        |
                        v
                   st7789.c (SPI)
                        |
                        v
                   TFT Display
```

---

## Configuration File Format

`scsettings.txt` uses a simple key=value format:

```
# Comments start with #
buffersize=1024
platterspeed=9100
brakespeed=3000
```

GPIO mappings use a special format:
```
gpio=port,pin,pull,edge,action
```

MIDI mappings:
```
midii=status,channel,data,edge,action
```

See the comments in `scsettings.txt` for full documentation of all parameters.

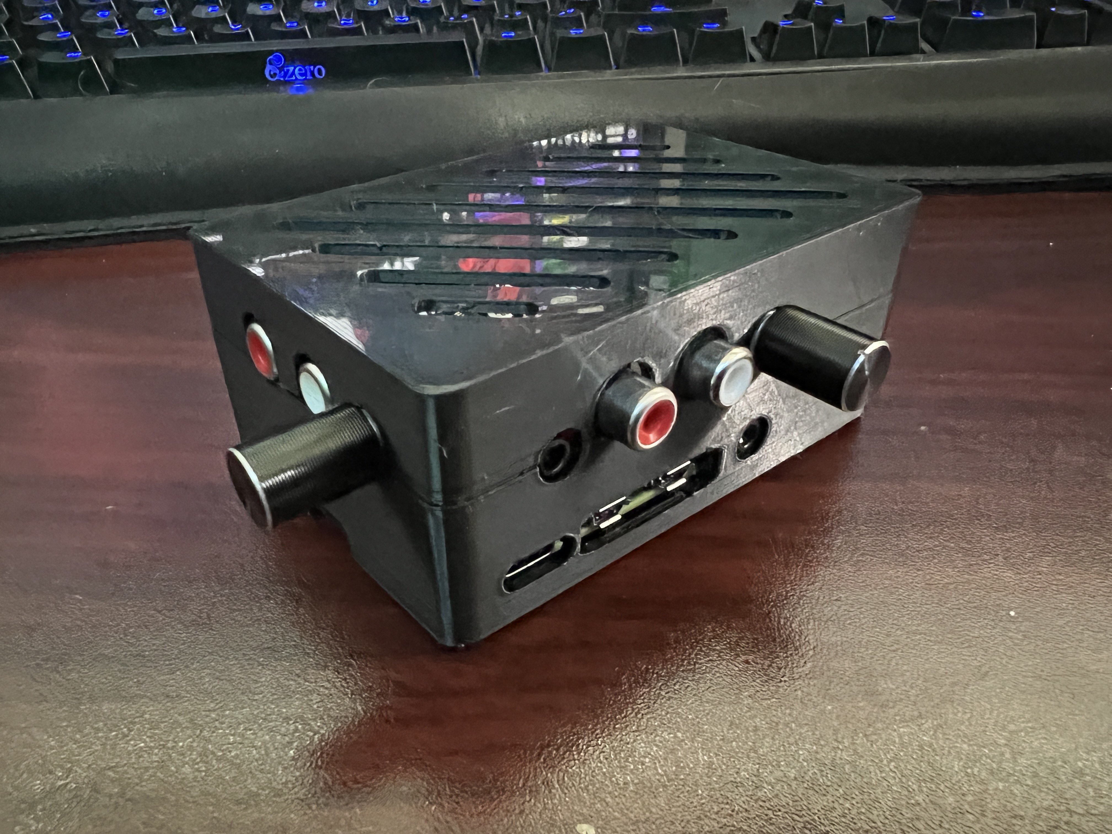
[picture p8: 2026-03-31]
docs/enclosure/audioinjector/images/4979aa02-84ee-4992-b82a-159aa5866b54.jpg

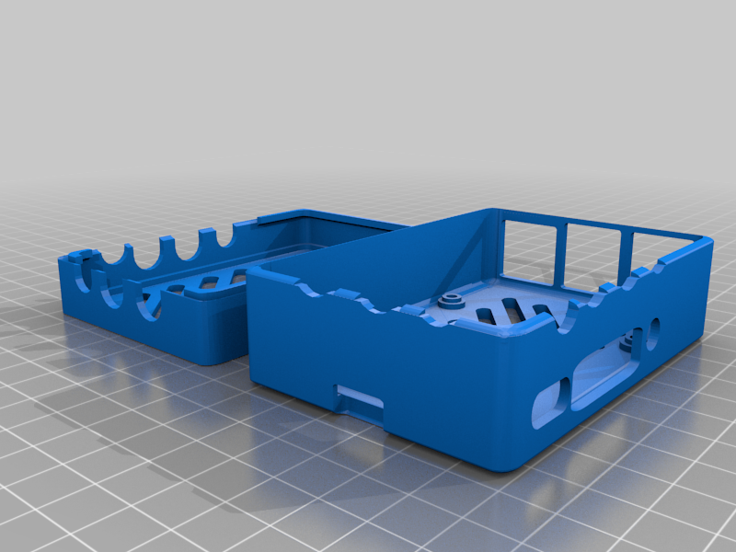
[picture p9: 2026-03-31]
docs/enclosure/audioinjector/images/87504e88-0ce6-4c34-a5fd-d9361a58694b.png

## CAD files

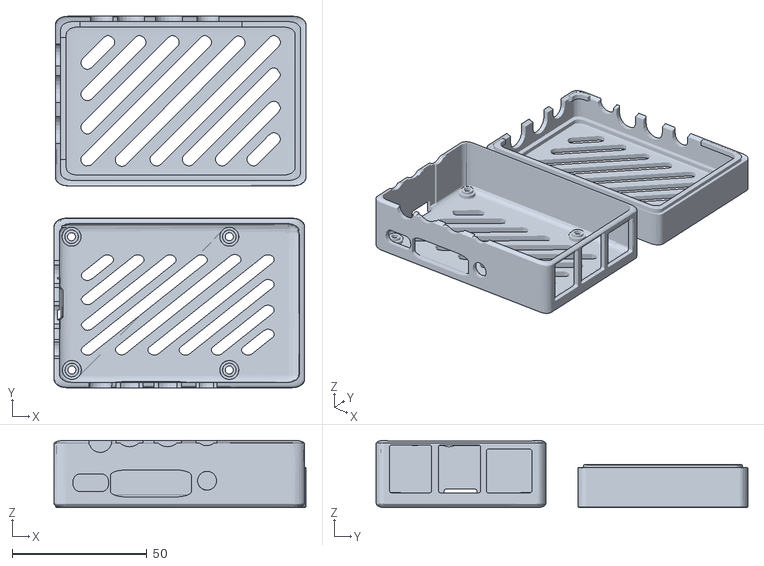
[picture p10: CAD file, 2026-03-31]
docs/enclosure/audioinjector/files/AudioInjector_Case_print.stl
93.6 x 138.0 x 25.0

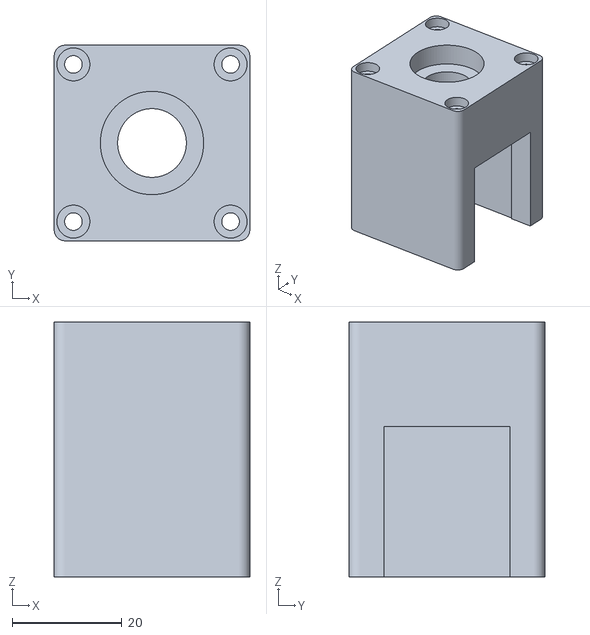
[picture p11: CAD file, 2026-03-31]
docs/enclosure/parametric_encoder_mount.stl
35.6 x 35.6 x 46.4

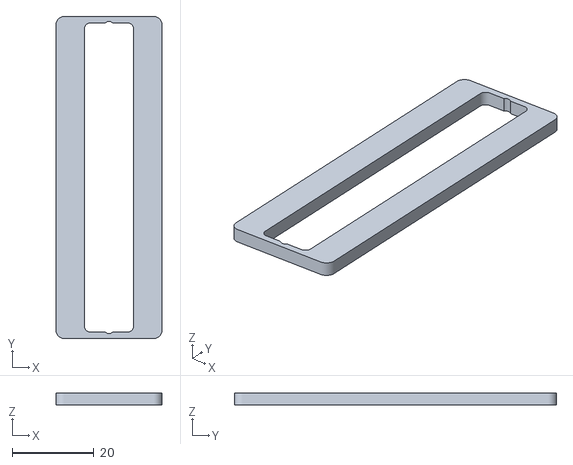
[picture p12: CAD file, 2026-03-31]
docs/enclosure/stls/button_bar_clamp.stl
25.9 x 78.7 x 3.00

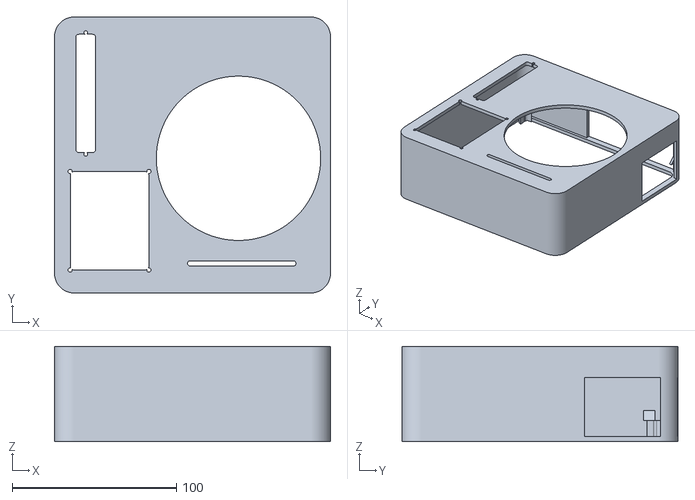
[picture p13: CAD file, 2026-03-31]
docs/enclosure/stls/base_shell.stl
168.0 x 168.0 x 58.0

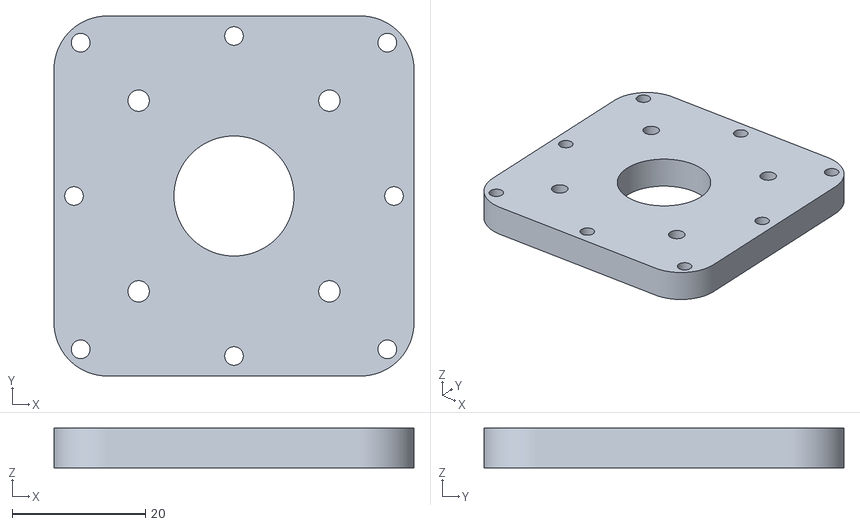
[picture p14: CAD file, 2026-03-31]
docs/enclosure/stls/platter_carrier.stl
54.0 x 54.0 x 6.00

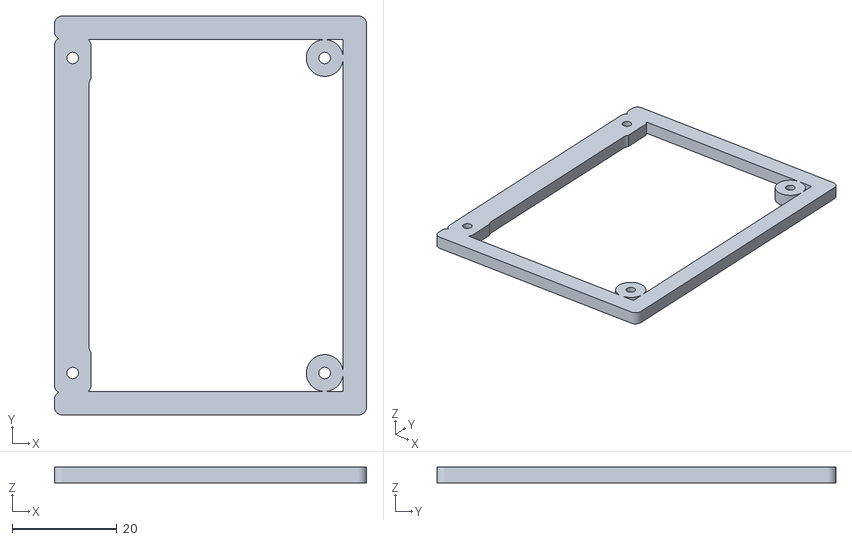
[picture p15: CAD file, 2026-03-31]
docs/enclosure/stls/display_clamp.stl
59.5 x 76.0 x 3.00

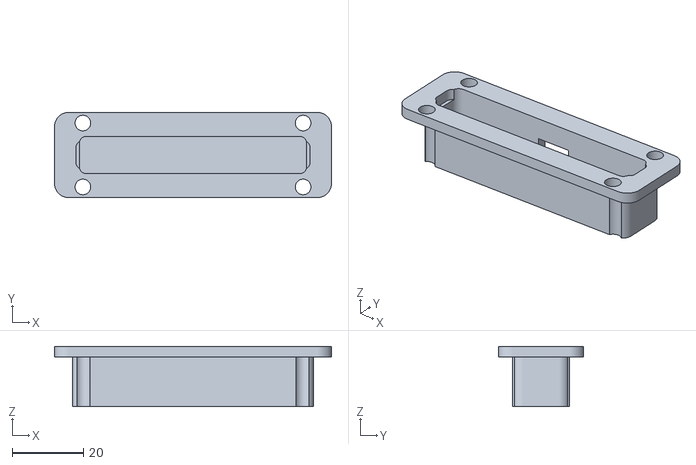
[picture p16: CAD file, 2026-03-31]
docs/enclosure/stls/fader_cassette.stl
78.0 x 24.0 x 17.0

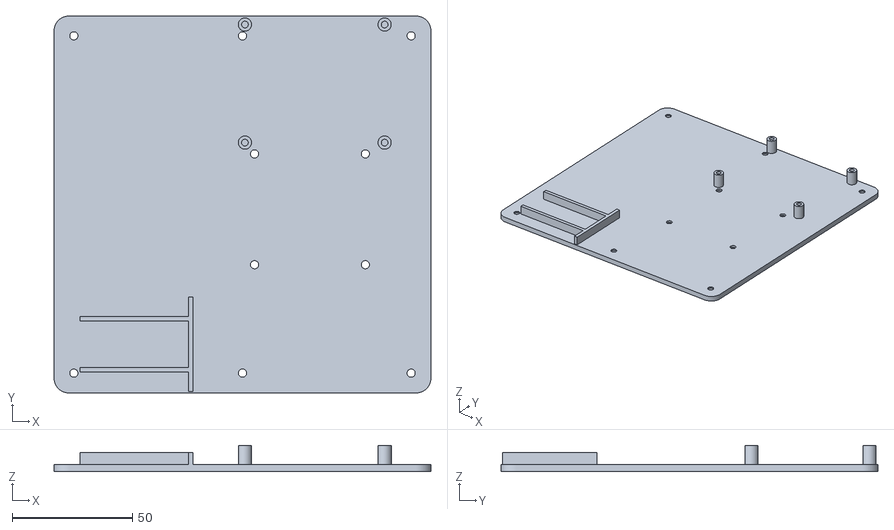
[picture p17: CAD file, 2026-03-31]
docs/enclosure/stls/bottom_cover.stl
156.5 x 156.5 x 11.0

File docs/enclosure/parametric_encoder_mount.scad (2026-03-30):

// Parametric MT6701 Encoder Mount
// ==================================
//
// This is a fully parametric version of the AS5600 adapted mount.
// All key dimensions can be changed, and the design recomputes automatically.
//
// Parts:
//   1. BASE: Holds PCB, bearing seat, mounting holes
//   2. CAP: Accommodates bolt head and washer
//   3. PLATTER: Adapter ring for platter support
//   4. BOLT: M5 bolt (not printed) with magnet at bottom end
//
// Assembly order:
//   1. Bearing into base seat
//   2. Drop bolt (with magnet) through bearing from top
//   3. PCB slides into base from below (position regulated for perfect air gap)
//   4. Cap press-fits onto bolt shaft
//   5. Platter adapter on cap body
//
// Key features:
//   - Bolt head sits directly above cap
//   - PCB position automatically regulated for perfect air gap
//   - All dimensions parametric for different bearings/shafts

$fn = $preview ? 32 : 80;

// =====================
// WHAT TO RENDER — change these, press F5
// =====================
// SHOW modes: "assembly" "exploded" "cross_section" "base" "cap" "platter" "print"
SHOW          = "base";
show_mock     = true;
show_labels   = false;
explode_gap   = 10;

// =====================
// PARAMETRIC DIMENSIONS
// =====================

// -- BEARING --
brg_bore     = 5.0;     // inner diameter (bore) - fits shaft
brg_od       = 18.5;    // outer diameter
brg_h        = 5.5;     // thickness
brg_tol      = 0.15;    // press-fit tolerance for seat

// -- BOLT (replaces plain shaft) --
bolt_dia      = 5.0;     // bolt shaft diameter - must fit bearing bore
bolt_length   = 24.0;    // bolt length (excluding head)
bolt_head_dia = 12.5;     // bolt head diameter (e.g., M5 socket head)
bolt_head_h   = 1.5;     // bolt head height


// -- MAGNET (at shaft end) --
mag_dia      = 4.0;     // diameter
mag_h        = 2.0;     // thickness
mag_tol      = 0.1;     // press-fit tolerance

// -- RETENTION (nut + washer below bearing) --
nut_h        = 4.2;     // M6 nut height
nut_af       = 10.0;    // M6 across flats
washer_h     = 1.6;     // M6 washer thickness
washer_od    = 12.0;    // M6 washer OD

// -- MT6701 PCB --
pcb_w        = 23.0;    // width
pcb_d        = 23.0;    // depth
pcb_t        = 1.6;     // thickness
pcb_tol      = 0.3;     // pocket tolerance
pcb_hole_spacing = 19.0; // M2 hole spacing
pcb_hole_dia = 2.2;     // M2 hole diameter

// -- AIR GAP --
air_gap      = 1.0;     // between IC and magnet (datasheet: 0.5-2.0mm)

// -- WALL THICKNESS --
wall         = 6.0;     // base wall thickness

// -- MOUNTING HOLES --
mount_hole_dia = 3.2;   // M3 mounting holes

// -- CAP (press-fits onto bolt shaft) --
cap_flange_dia = 25.0;  // top retention flange
cap_flange_h   = 2.0;   // flange thickness
cap_body_dia   = 20.0;  // main body diameter
cap_body_h     = 6.0;   // body height
cap_bore_tol   = 0.1;   // press-fit tolerance for bolt shaft

// -- PLATTER ADAPTER --
platter_dia    = 52.0;  // support diameter for platter
platter_h      = 2.0;   // thickness
platter_bore_tol = 0.1; // clearance fit over cap body

// -- BASE EXTENSIONS --
mount_drop     = 25.3;   // extra depth below PCB for mounting
dupont_clearance = 23.0; // minimum clearance below PCB for DuPont connectors

// =====================
// COMPUTED GEOMETRY
// =====================

// Bearing seat (with tolerance)
brg_seat_dia = brg_od + brg_tol * 2;

// Magnet pocket (with tolerance)
mag_pocket_dia = mag_dia + mag_tol * 2;

// PCB pocket (with tolerance)
pcb_pocket_w = pcb_w + pcb_tol * 2;
pcb_pocket_d = pcb_d + pcb_tol * 2;

// Center hole - must clear bolt shaft + nut + washer stack
center_hole = max(washer_od + 0.5, bolt_dia + 2.0); // clears nut/washer or bolt

// Base outer dimensions
base_outer = max(max(pcb_pocket_w, pcb_pocket_d) + wall * 2, brg_seat_dia + wall * 2);

// Vertical stack:
// Cap/bearing positions are fixed relative to each other.
// Bolt head seats on the cap, magnet sits at the very bottom of the bolt,
// and the PCB is solved downward from the magnet using the requested air gap.
mag_to_nut_clearance = 0.3;
pcb_ledge_min_z = mount_drop + 0.5;                 // minimum structure below PCB

// Relative positions, using bearing top as Z=0 before final offset.
brg_top_rel       = 0;
brg_bot_rel       = brg_top_rel - brg_h;
cap_bot_rel       = brg_top_rel;
cap_top_rel       = cap_bot_rel + cap_body_h;
bolt_head_bot_rel = cap_top_rel;
bolt_head_top_rel = bolt_head_bot_rel + bolt_head_h;
washer_top_rel    = brg_bot_rel;
washer_bot_rel    = washer_top_rel - washer_h;
nut_top_rel       = washer_bot_rel;
nut_bot_rel       = nut_top_rel - nut_h;
bolt_shank_bot_rel = cap_top_rel - bolt_length;     // head seated on cap top
mag_bot_rel       = bolt_shank_bot_rel;             // magnet sits at bolt bottom
mag_top_rel       = mag_bot_rel + mag_h;
pcb_top_rel       = mag_bot_rel - air_gap;
pcb_ledge_rel     = pcb_top_rel - pcb_t;

// Shift the whole mount upward so the PCB still has the requested lower support.
z_offset      = pcb_ledge_min_z - pcb_ledge_rel;
pcb_ledge_z   = pcb_ledge_rel + z_offset;
pcb_top_z     = pcb_top_rel + z_offset;
mag_bot_z     = mag_bot_rel + z_offset;
mag_top_z     = mag_top_rel + z_offset;
nut_bot_z     = nut_bot_rel + z_offset;
nut_top_z     = nut_top_rel + z_offset;
washer_bot_z  = washer_bot_rel + z_offset;
washer_top_z  = washer_top_rel + z_offset;
brg_bot_z     = brg_bot_rel + z_offset;
brg_top_z     = brg_top_rel + z_offset;
cap_bot_z     = cap_bot_rel + z_offset;
cap_top_z     = cap_top_rel + z_offset;
bolt_head_bot_z = bolt_head_bot_rel + z_offset;
bolt_head_top_z = bolt_head_top_rel + z_offset;
bolt_shank_bot_z = bolt_shank_bot_rel + z_offset;
base_h        = brg_top_z;

// Diagnostics
required_bolt_length = cap_body_h + brg_h + washer_h + nut_h + mag_h + mag_to_nut_clearance;
mag_to_nut_gap = nut_bot_z - mag_top_z;             // free shank between magnet and nut
bolt_below_brg = brg_bot_z - bolt_shank_bot_z;      // total bolt shank below bearing
bolt_above_brg = bolt_head_bot_z - brg_top_z;       // shank above bearing up to the cap

// Cap bore (press-fit onto bolt shaft)
cap_bore = bolt_dia + cap_bore_tol;

// Platter bore (clearance fit over cap body)
platter_bore = cap_body_dia + platter_bore_tol;

// Verification echoes
echo("=== PARAMETRIC MT6701 MOUNT DIMENSIONS ===");
echo(str("Bearing: ", brg_bore, "mm bore, ", brg_od, "mm OD, ", brg_h, "mm thick"));
echo(str("Bolt: M", brg_bore, " x ", bolt_length, "mm (", bolt_below_brg, "mm below brg, ", bolt_above_brg, "mm above)"));
echo(str("Bolt head: ", bolt_head_dia, "mm dia x ", bolt_head_h, "mm (sits on cap)"));
echo(str("Magnet: ", mag_dia, "mm dia x ", mag_h, "mm thick at bolt end"));
echo(str("Base: ", base_outer, "mm x ", base_outer, "mm x ", base_h, "mm"));
echo(str("Center hole: ", center_hole, "mm (clears bolt + retention)"));
echo(str("Air gap: ", air_gap, "mm between PCB and magnet"));
echo(str("PCB top: ", pcb_top_z, "mm, magnet bottom: ", mag_bot_z, "mm"));
echo(str("Magnet-to-nut gap: ", mag_to_nut_gap, "mm"));
if (mag_to_nut_gap < mag_to_nut_clearance)
    echo(str("WARNING: bolt_length is ", mag_to_nut_clearance - mag_to_nut_gap,
             "mm too short for the magnet + nut stack."));

// =====================
// PRINTABLE PARTS
// =====================

// BASE: Main mounting structure
module mount_base() {
    difference() {
        // Main block with rounded corners for better strength
        hull() {
            translate([-base_outer/2 + 2, -base_outer/2 + 2, 0])
                cylinder(r=2, h=base_h);
            translate([base_outer/2 - 2, -base_outer/2 + 2, 0])
                cylinder(r=2, h=base_h);
            translate([-base_outer/2 + 2, base_outer/2 - 2, 0])
                cylinder(r=2, h=base_h);
            translate([base_outer/2 - 2, base_outer/2 - 2, 0])
                cylinder(r=2, h=base_h);
        }

        // PCB pocket (open from below, PCB rests on ledge)
        translate([-pcb_pocket_w/2, -pcb_pocket_d/2, -0.1])
            cube([pcb_pocket_w, pcb_pocket_d, pcb_top_z + 0.1]);

        // DuPont connector clearance (side exit at PCB level)
        translate([0, -dupont_clearance/2, -0.1])
            cube([base_outer/2 + 1, dupont_clearance, pcb_top_z + 0.1]);

        // Center hole (clears shaft + nut + washer)
        translate([0, 0, pcb_top_z - 0.1])
            cylinder(d=center_hole, h=brg_bot_z - pcb_top_z + 0.2);

        // Bearing seat (press-fit with chamfer for easy insertion)
        translate([0, 0, brg_bot_z])
            cylinder(d=brg_seat_dia, h=brg_h + 1.0);
        // Chamfer for bearing insertion
        translate([0, 0, brg_bot_z - 0.5])
            cylinder(d1=brg_seat_dia + 2, d2=brg_seat_dia, h=0.5);
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

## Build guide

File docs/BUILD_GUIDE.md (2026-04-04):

# ScratchTJ MK2 Build Guide

This guide covers the **new improved MK2 build** only.
If you are looking for the old version, use Git tag **`mk1`**.

---

## 1) Build Goal

Build a compact digital scratch deck around:

- Raspberry Pi + xwax engine
- Touch-sensitive metal platter
- Crossfader + cue buttons
- Rotary navigation + TFT menu
- MT6701 magnetic angle sensing for platter position

MK2 finished build -- platter, TFT display, buttons, and fader

---

## 2) System Wiring Diagram

This is the full signal path -- every connection between components:

```
                          ┌─────────────────────────────────────────────┐
                          │              RASPBERRY PI                    │
                          │                                             │
  ┌──────────────┐        │  GPIO 2 (SDA) ◄──── I2C ────► MT6701      │
  │ AudioInjector│◄─I2S──►│  GPIO 3 (SCL) ◄─────┘         (0x06)      │
  │  Sound Card  │        │                                             │
  │  (HAT)       │        │  GPIO 10 (MOSI) ──► SPI ────► ST7789 TFT  │
  └──────────────┘        │  GPIO 11 (SCLK) ──►    │      (240x240)   │
        │                 │  GPIO 8  (CE0)  ──► CS  │                   │
     3.5mm                │  GPIO 24        ──► DC  │                   │
     jacks                │  GPIO 25        ──► RST │                   │
                          │                                             │
                          │  GPIO 22 (DT)  ◄── EC11 Rotary Encoder     │
                          │  GPIO 23 (CLK) ◄──   (menu navigation)     │
                          │  GPIO 27 (SW)  ◄──   (push button)         │
                          │                                             │
                          │  GPIO 17       ◄── KB0 Button (back)       │
                          │                                             │
                          │  USB ◄──────────────── USB Serial 500kbaud  │
                          └───────────────────┬────────────────────────┘
                                              │
                                              ▼
                                    ┌─────────────────┐
                                    │  ARDUINO NANO    │
                                    │                  │
                                    │  A5 ◄── Fader    │  (60mm crossfader)
                                    │                  │
                                    │  D10 ── 1.2kΩ ──┤
                                    │  D12 ◄───────── spring contact
                                    │                     │
                                    │  A0 ◄── Cue Btn 1   │ slip ring
                                    │  A1 ◄── Cue Btn 2   │
                                    │  A2 ◄── Cue Btn 3   ▼
                                    │  A3 ◄── Cue Btn 4  HDD Platter
                                    └─────────────────┘  (user touches)
```

**Note:** The Arduino connects to the Pi via USB cable (CH340 USB-serial chip). No GPIO serial wiring or level shifters needed.

---

## 3) GPIO Pin Map

Every GPIO pin used by the system:

| Pi GPIO | Function | Protocol | Direction |
|---|---|---|---|
| 2 | MT6701 SDA | I2C | Bidirectional |
| 3 | MT6701 SCL | I2C | Output |
| 8 | TFT CS (CE0) | SPI | Output |
| 10 | TFT MOSI | SPI | Output |
| 11 | TFT SCLK | SPI | Output |
| 17 | KB0 button (select/confirm) | GPIO | Input (pull-up) |
| 22 | Menu encoder DT | GPIO | Input |
| 23 | Menu encoder CLK | GPIO | Input |
| 24 | TFT DC | GPIO | Output |
| 25 | TFT RST | GPIO | Output |
| 27 | Menu encoder SW | GPIO | Input (pull-up) |

| Arduino Pin | Function | Notes |
|---|---|---|
| A5 | Fader | Analog read, 10-bit |
| D10 | Cap touch send | CapacitiveSensor library |
| D12 | Cap touch sense | Via 1.2kΩ to D10 |
| A0--A3 | Cue buttons 1--4 | Digital read, internal pull-up |
| USB | Serial to Pi | 500,000 baud via CH340 (`/dev/ttyUSB0`) |

---

## 4) Hardware Stack

### Main electronics
- Raspberry Pi (2/3/4)
- AudioInjector sound card/HAT
- Arduino Nano (for fader + touch signal path)
- MT6701 magnetic encoder module (I2C)
- ST7789 240x240 TFT (SPI)
- Rotary encoder (menu navigation)
- 60mm DJ-style crossfader
- Cue buttons (4x, active-low)

### Mechanical
- HDD platter and bearing support
- Slip ring/spring contact for platter touch transfer
- 3D printed MK2 enclosure parts

Internals -- wiring, AudioInjector sound card, and platter mount visible

---

## 5) Enclosure

The enclosure is a 3D printed shell that holds all the electronics and the platter assembly. The platter opening is on top, controls face upward for natural DJ interaction.

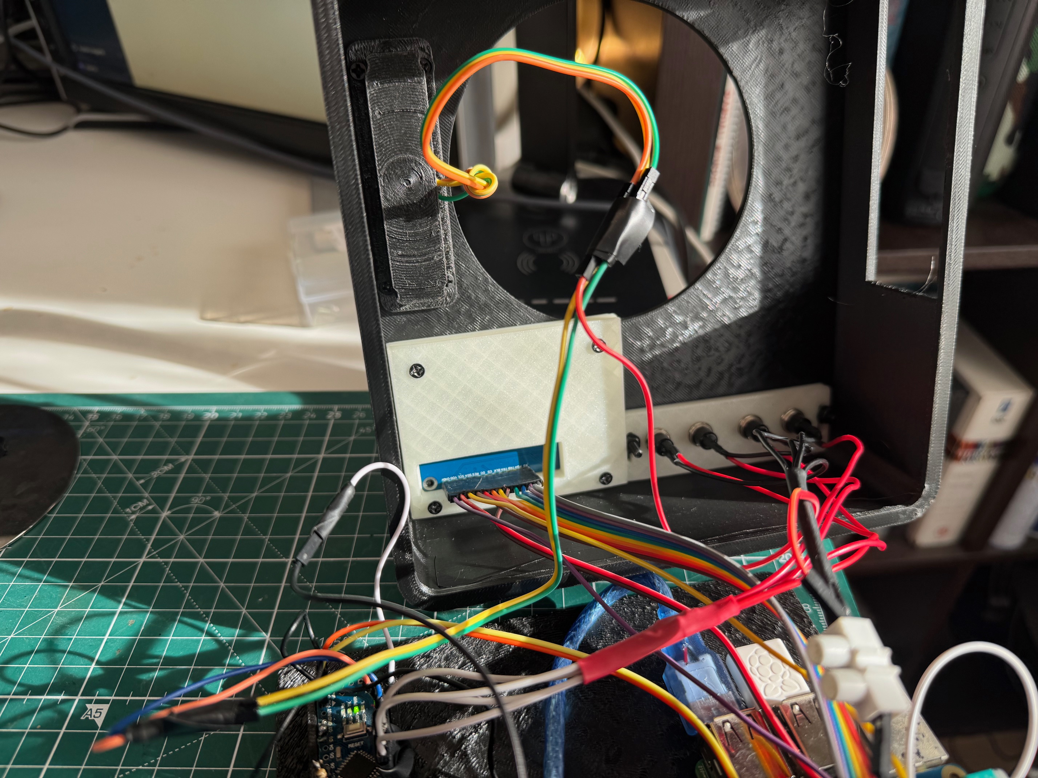
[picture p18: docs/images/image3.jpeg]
Enclosure side view -- platter opening and Arduino mounting area


### A note on fit

The current 3D printed enclosure design works but it is rough around the edges. M3 screws need to be forced into their holes -- expect to brute-force them in. The tolerances are not dialed in and the design could use a proper revision. That said, once the screws are in, the assembly is sturdy enough and holds up fine under scratching. It's functional, not pretty.

See [`enclosure/ENCLOSURE_DESIGN.md`](enclosure/ENCLOSURE_DESIGN.md) for full enclosure documentation.

---

## 6) Parametric Encoder Mount

The encoder mount is the core mechanical component of MK2. It holds the MT6701 magnetic angle sensor, bearing, shaft, and magnet in precise alignment. The design is fully parametric in OpenSCAD -- every dimension can be changed and the geometry recomputes automatically.

Source file: [`enclosure/parametric_encoder_mount.scad`](enclosure/parametric_encoder_mount.scad)
Pre-built STL: [`enclosure/parametric_encoder_mount.stl`](enclosure/parametric_encoder_mount.stl)

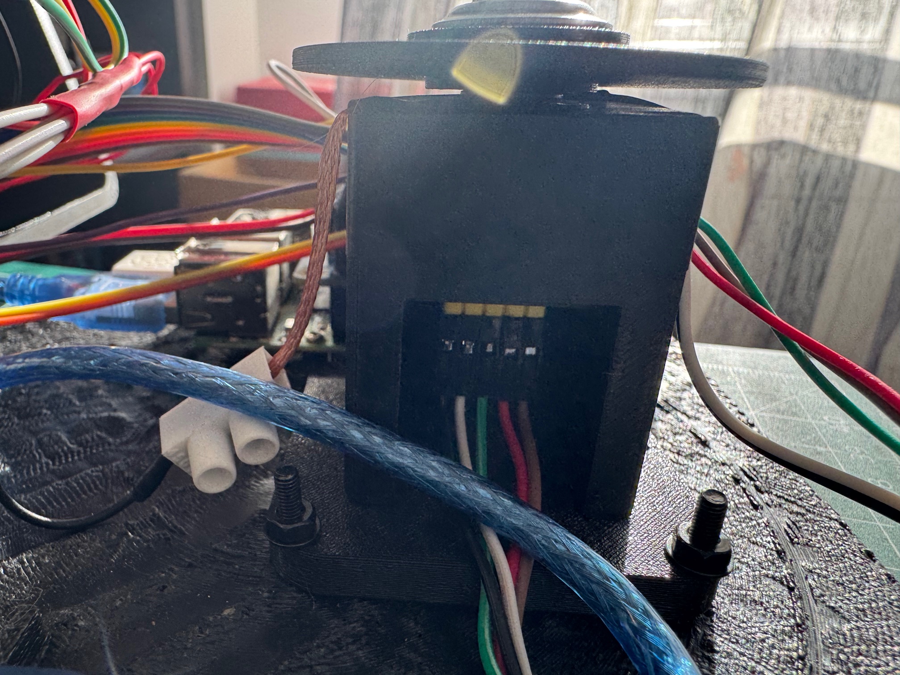
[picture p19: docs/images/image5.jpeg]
Encoder mount side view -- I2C header pins and magnet area visible


### Design overview

The mount is a three-part printed assembly plus off-the-shelf hardware:

```
        ┌─────────────────┐
        │   HDD PLATTER   │  (metal disc, user touches this)
        ├─────────────────┤
        │ PLATTER ADAPTER │  (printed, sits on cap flange)
        ├─────────────────┤
        │      CAP        │  (printed, press-fits onto bolt shaft)
        │   ┌─────────┐   │
        │   │BOLT HEAD│   │  (M5 socket head, sits on cap top)
        ├───┼─────────┼───┤
        │   │  SHAFT  │   │
        │   │ (bolt)  │   │  ← bearing press-fit zone
        │ ┌─┤         ├─┐ │
        │ │ │ BEARING │ │ │  (e.g. 625: 5mm bore, 16mm OD)
        │ └─┤         ├─┘ │
        │   │         │   │
        │   │  SHAFT  │   │
        │   │ (bolt)  │   │
        │   ├─────────┤   │
        │   │ WASHER  │   │
        │   ├─────────┤   │
        │   │   NUT   │   │  (retains bolt below bearing)
        │   ├─────────┤   │
        │   │ MAGNET  │   │  (diametric, at bolt bottom end)
        │   └────┬────┘   │
        │     air gap      │
        │   ┌────┴────┐   │
        │   │ MT6701  │   │  (PCB, slides in from below)
        │   │   PCB   │   │
        │   └─────────┘   │
        │      BASE        │  (printed, holds everything)
        └─────────────────┘
```

Encoder mount exploded view in OpenSCAD -- base, bearing, bolt with magnet, cap, and platter adapter

### The shaft: why an M5 bolt

The shaft is simply an **M5 bolt** that passes through the bearing bore. This is the key design choice:

- An M5 bolt has a 5mm shank that fits standard 625 bearings (5mm bore) with no machining
- The bolt head provides a natural stop above the cap
- A nut and washer below the bearing retain the bolt and set the vertical position
- The diametric magnet press-fits into a pocket at the bottom end of the bolt, directly above the MT6701 sensor IC

Any M5 bolt works as long as it is long enough. The minimum bolt length is computed automatically by the OpenSCAD model based on the bearing height, cap height, washer, nut, and magnet stack. With the default parameters, a 24mm M5 socket head cap screw is used.

### Bearing

The default bearing is a **625** (also called 625ZZ):
- 5mm bore (fits M5 bolt)
- 16mm outer diameter
- 5mm thick

The bearing press-fits into a seat in the base. A 0.15mm tolerance is added for a snug fit. A chamfer at the top of the seat makes insertion easier. Any bearing with a 5mm bore can be used -- just change `brg_od` and `brg_h` in the SCAD file.

### MT6701 PCB positioning

The MT6701 sensor must be positioned at a precise distance below the magnet. The datasheet specifies a 0.5--2.0mm air gap between the IC and the magnet face. The default is **1.0mm**.

The PCB slides into the base from below and rests on a ledge. The ledge height is **computed automatically** from the air gap parameter, magnet size, nut/washer stack, and bearing position. This means if you change any dimension (different bearing, different magnet thickness, different air gap), the PCB position adjusts to maintain the correct sensing distance.

The PCB pocket accommodates a 23mm x 23mm MT6701 breakout board with M2 mounting holes on 19mm spacing. There is 23mm of clearance below the PCB for DuPont connectors.

### Three printed parts

**1. Base** -- the main structure

Holds the bearing seat at the top, PCB pocket at the bottom, and M3 corner mounting holes for attaching to the enclosure. The base dimensions are computed from the PCB size plus wall thickness or bearing OD plus wall thickness, whichever is larger.

**2. Cap** -- the spinning top piece

Press-fits onto the M5 bolt shaft above the bearing. Has a flange at the top that acts as a retention surface and platter support. The bore tolerance is 0.1mm for a snug press-fit.

**3. Platter adapter** -- optional centering ring

Sits on the cap body and centers the HDD platter. Clearance fit over the cap body diameter.

### Assembly order

1. Press the bearing into the base seat
2. Attach the diametric magnet to the bottom of the M5 bolt (glue or press-fit pocket)
3. Drop the bolt through the bearing from the top
4. From below: add washer, then nut, tighten to set position
5. Slide the MT6701 PCB into the base from below (it rests on the computed ledge)
6. Press-fit the cap onto the bolt shaft above the bearing
7. Place the platter adapter on the cap, then the HDD platter on top

### Parametric dimensions

All dimensions are in the SCAD file header. The most commonly adjusted ones:

| Parameter | Default | Description |
|---|---|---|
| `brg_bore` | 5.0mm | Bearing inner diameter (must match bolt) |
| `brg_od` | 18.5mm | Bearing outer diameter |
| `brg_h` | 5.5mm | Bearing thickness |
| `bolt_dia` | 5.0mm | Bolt shaft diameter |
| `bolt_length` | 24.0mm | Bolt length excluding head |
| `bolt_head_dia` | 12.5mm | Bolt head diameter |
| `mag_dia` | 4.0mm | Diametric magnet diameter |
| `mag_h` | 2.0mm | Magnet thickness |
| `air_gap` | 1.0mm | Gap between IC and magnet (datasheet: 0.5--2.0mm) |
| `pcb_w` / `pcb_d` | 23.0mm | MT6701 breakout board dimensions |
| `pcb_hole_spacing` | 19.0mm | M2 mounting hole spacing |
| `cap_body_dia` | 20.0mm | Cap diameter |
| `platter_dia` | 52.0mm | Platter adapter support diameter |
| `wall` | 6.0mm | Base wall thickness |

### OpenSCAD render modes

Change the `SHOW` variable at the top of the file:

| Mode | Description |
|---|---|
| `"assembly"` | All parts assembled with mock hardware |
| `"exploded"` | Exploded view with labels |
| `"cross_section"` | Cross-section cut through center |
| `"base"` | Base part only (for export/print) |
| `"cap"` | Cap part only |
| `"platter"` | Platter adapter only |
| `"print"` | All printed parts laid out for printing |

Set `show_mock = true` to include bearing, bolt, magnet, nut, washer, and PCB visualizations.

### Print settings

| Part | Layer height | Walls | Infill | Supports |
|---|---|---|---|---|
| Base | 0.2mm | 3 | 20% | No |
| Cap | 0.16mm | 4 | 80% | No |
| Platter adapter | 0.2mm | 2 | 15% | No |

Use PETG for all parts -- it has better layer adhesion and heat resistance than PLA, which matters for the bearing press-fit.

---

## 7) Platter Sensing -- MT6701 Hall Sensor

MK2 uses an **MT6701 magnetic angle sensor** (Hall-based, 14-bit resolution) rather than the MK1 optical encoder.

### How it works
1. The diametric magnet rotates with the platter (attached to the M5 bolt in the encoder mount)
2. The MT6701 PCB is fixed below at a calibrated air gap
3. As the platter rotates, the sensor reads absolute angular position (0--16383)
4. Raspberry Pi reads angle data over I2C at address `0x06` (registers 0x03--0x04)
5. Software converts angle deltas into jog/scratch control for xwax

### I2C wiring

| MT6701 Pin | Pi Pin |
|---|---|
| VCC | 3.3V |
| GND | GND |
| SDA | GPIO 2 (SDA1) |
| SCL | GPIO 3 (SCL1) |

Verify with: `i2cdetect -y 1` -- should show `06` at address 0x06.

### Why this works well
- No slotted optical wheel needed -- just a magnet and a PCB
- 14-bit resolution (16384 steps per revolution) vs 2400 CPR on the old optical encoder
- Absolute position -- no homing or drift
- Contactless -- no mechanical wear on the sensing path
- Compact -- the entire sensor is inside the encoder mount base

### Alignment notes
- Keep the magnet centered over the sensor IC axis
- Keep the air gap consistent through full rotation (the bearing handles this)
- Avoid tilt between the magnet plane and sensor board
- Route power/noisy wires away from the I2C lines (SDA/SCL)

---

## 8) Capacitive Touch (Platter Contact)

The platter must be electrically connected to the Arduino so it can detect when the user's finger is touching the metal. Since the platter rotates freely on a bearing, a slip ring transfers the signal from the spinning platter to a fixed wire.

### Circuit

```
                     1.2kΩ
Arduino D10 ────────/\/\/\/──────── Arduino D12 ──── wire ──── spring contact
  (send)                              (sense)                       │
                                                              copper slip ring
                                                              (rotates with hub)
                                                                    │
                                                              soldered wire
                                                                    │
                                                              HDD PLATTER
                                                              (metal, user touches)
                                                                    │
                                                              user's finger
                                                              (body capacitance)
```

The Arduino `CapacitiveSensor` library sends a pulse on D10 and measures how long it takes to charge through the 1.2kΩ resistor to D12. When nobody is touching the platter, the reading is low (~100--500). When a finger touches the metal platter, body capacitance increases the charge time and the reading jumps (~5000--30000).

### Slip ring construction

The slip ring is built into the rotor hub of the encoder mount:

1. **Copper tape ring** -- 3mm wide adhesive copper tape wrapped into the groove on the rotor hub (full circle, overlapping ends)
2. **Wire from ring to platter** -- a thin wire soldered to the copper ring, routed through the hub's wire channel to the platter contact point on the flange
3. **Spring contact** -- a phosphor bronze strip (0.1--0.2mm thick, 3mm wide) mounted in a fixed holder, curved tip pressing against the copper ring as it spins
4. **Wire from spring to Arduino** -- soldered to the flat end of the spring strip, connects to D12

### Touch thresholds

Configured via the on-device menu (Config > Global Settings):

| Parameter | Default | Description |
|---|---|---|
| `cap_threshold` | 5000 | Reading above this = touched |
| `cap_hysteresis` | 500 | Band between touch-on and touch-off to prevent flicker |

Touch state gates scratch behavior -- platter movement only affects audio when the platter is being touched (depending on mode).

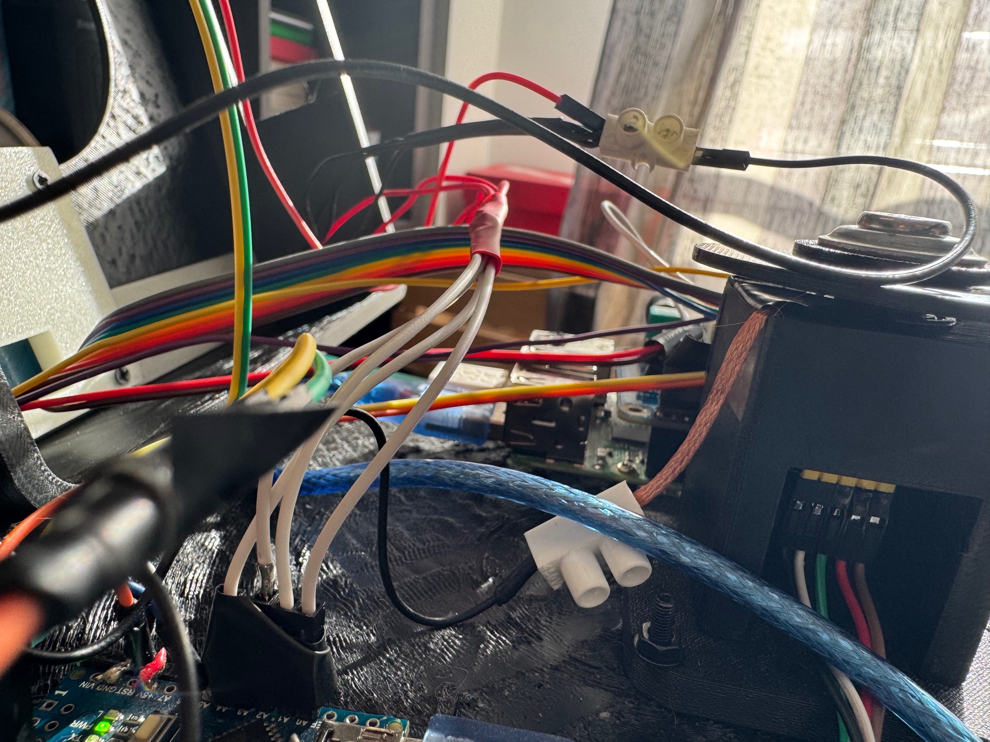
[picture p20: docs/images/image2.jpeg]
Internal wiring -- ribbon cables, serial connection, encoder mount from behind


---

## 9) Arduino Nano

The Arduino Nano handles the DJ crossfader (analog on A5), capacitive touch sensor (D10/D12), and 4 cue buttons (A0--A3). It sends all data to the Pi over serial.

Arduino Nano in its 3D printed cradle -- the 1.2kΩ resistor and the wire going to the platter spring contact are both soldered to the same D12 sense pin

The Nano sits in a friction-fit 3D printed cradle inside the enclosure. The USB port remains accessible from the side for firmware updates.

### Serial connection

Connect the Arduino Nano to one of the Pi's USB ports with a USB cable. The CH340 USB-serial chip on the Nano appears as `/dev/ttyUSB0`. The USB cable provides both data and 5V power -- no separate wiring needed.

Baud rate: **500,000**. No GPIO serial or `raspi-config` serial setup required.

### Packet format (7 bytes)

```
Byte:  [0]     [1]     [2]     [3]     [4]     [5]       [6]
       SYNC    fHi     fLo     capHi   capLo   buttons   XOR
       0xAA    ──fader──       ──cap touch──    4-bit     checksum
               (10-bit)        (16-bit)         bitfield  (bytes 1-5)
```

Handshake: Pi sends `0x53` ('S'), Arduino replies `'T'`. Watchdog on the Pi detects 2-second timeouts with DTR hard-reset of the Arduino after 3 consecutive failures.

### Flashing

1. Connect Nano via USB
2. Open `arduino_nano/arduino_nano.ino` in Arduino IDE
3. Install `CapacitiveSensor` library
4. Select board: **Arduino Nano** (ATmega328P, Old Bootloader for CH340 clones)
5. Upload

Both the Arduino firmware and Pi software must be updated together since they share the binary serial protocol.

---

## 10) TFT Display (ST7789)

The ST7789 240x240 TFT replaces the MK1's 1602A LCD. It connects over SPI.

### Wiring

| TFT Pin | Pi Pin |
|---|---|
| VCC | 3.3V |
| GND | GND |
| SCL | GPIO 11 (SPI0_SCLK) |
| SDA | GPIO 10 (SPI0_MOSI) |
| DC | GPIO 24 |
| RST | GPIO 25 |
| CS | GPIO 8 (SPI0_CE0) |
| BLK | 3.3V (or GPIO for dimming) |

Enable SPI in `raspi-config`. Test with: `make test_tft_ui && sudo ./test_tft_ui`

---

## 11) Menu Encoder and Buttons

### EC11 rotary encoder (menu navigation)

| Encoder Pin | Pi Pin |
|---|---|
| CLK | GPIO 23 |
| DT | GPIO 22 |
| SW (push) | GPIO 27 |
| GND | GND |

Rotation scrolls menu items. Short press = back/cancel. Long press (500ms) = switch active deck.

### KB0 button

| Button | Pi Pin |
|---|---|
| KB0 (back) | GPIO 17 |

Short press = select/confirm/enter submenu. Active-low with internal pull-up.

### Cue buttons (on Arduino)

| Button | Arduino Pin |
|---|---|
| Cue 1 | A0 |
| Cue 2 | A1 |
| Cue 3 | A2 |
| Cue 4 | A3 |

Active-low with internal pull-ups. Button states are sent to the Pi as a 4-bit bitfield in byte 5 of the serial packet. Button behavior depends on the active function mode: in **CUE mode**, short press = jump to cue point, long press = set cue. In **SETTINGS mode**, buttons control pitch, platter speed, start/stop, and volume (hold + rotate platter to adjust).

---

## 12) Fader

The DJ crossfader connects to Arduino analog pin A5. The 10-bit ADC reading (0--1023) is sent to the Pi as bytes 1--2 of the serial packet. Software applies a configurable fader curve (factor, power, direction) to map the raw value to audio crossfade.

The current build uses a cheap 60mm DJ fader. It works, but a professional fader would be a significant upgrade for scratch feel and cut precision.

Good options:
- **Innofader PNP** -- contactless magnetic fader, zero bleed, extremely precise cut-in
- **Jesse Dean JDDX2RS-A** -- popular in the portablist community, tight cut-in, reliable

Either would require redesigning the fader support (the 3D printed part that holds the fader in the enclosure). The fader slot dimensions and mounting hole pattern differ from the generic 60mm fader, so a new support piece would need to be modeled. This is a relatively contained change -- the rest of the enclosure and electronics stay the same, only the fader mount geometry changes.

---

## 13) Software Build

```bash
cd ~/ScratchTJ/software
make -j4
sudo LC_ALL=en_GB.utf8 nice -n -19 ./xwax
```

For full installation instructions (packages, interfaces, AudioInjector setup, ALSA config, audio file preparation), see [`INSTALLATION.md`](INSTALLATION.md).

---

## 14) Validation Checklist

After assembly, verify each subsystem:

| Check | How to verify |
|---|---|
| Platter spins freely | Spin by hand, no rubbing or grinding |
| MT6701 detected | `i2cdetect -y 1` shows `06` |
| MT6701 angle changes | `i2cget -y 1 0x06 0x03 w` changes as you spin |
| Touch works | Serial monitor shows cap values jump on touch |
| Fader works | Serial monitor shows fader bytes change |
| Cue buttons work | Serial monitor shows button bitfield change |
| TFT displays | `sudo ./test_tft_ui` shows test pattern |
| Audio output | `aplay -l` shows AudioInjector, `speaker-test` produces sound |
| Menu responds | Encoder rotates through menu, KB0 exits |
| Scratching works | Load a track, touch platter, move it, hear audio respond |

MK2 finished -- alternate angle showing TFT menu active

---

## 15) Share Your Build

When your build is ready, post it:

- **Reddit**: build log + scratch clip, mention ScratchTJ MK2 and link this repo
- **Discord**: 15--45s scratch demo, wiring photo, key settings (buffer, platter speed, touch threshold)

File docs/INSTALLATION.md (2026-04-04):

# ScratchTJ MK2 -- Installation & Setup Guide

## 1. Raspberry Pi Setup

### Operating System

Install Raspberry Pi OS (Lite or Desktop). Tested on Raspbian Buster and Bullseye.

```bash
# Update system
sudo apt update && sudo apt upgrade -y

# Install build dependencies and runtime packages
sudo apt install -y build-essential libasound2-dev libsdl2-dev \
  git i2c-tools ffmpeg mpg123 sox
```

### Required Packages

| Package | Purpose |
|---|---|
| `build-essential` | GCC compiler and make |
| `libasound2-dev` | ALSA audio development headers |
| `libsdl2-dev` | SDL2 development headers (display/input) |
| `git` | Source control |
| `i2c-tools` | I2C diagnostics (`i2cdetect`, `i2cget`) |
| `ffmpeg` | Audio decoding for WAV/FLAC/OGG import |
| `mpg123` | MP3 decoding for track import |
| `sox` | Audio utilities |

### Enable Interfaces

```bash
sudo raspi-config
```

Enable:
- **I2C** (for MT6701 encoder)
- **SPI** (for ST7789 TFT display)
- **Serial** is no longer needed for Arduino communication (now uses USB serial via `/dev/ttyUSB0`)

Reboot after changes.

### AudioInjector HAT

Install the AudioInjector sound card overlay:

```bash
# Add to /boot/config.txt:
dtoverlay=audioinjector-wm8731-audio

# Reboot and verify
aplay -l
# Should show "audioinjector" device
```

Configure ALSA mixer defaults:

```bash
amixer -c 0 sset 'Output Mixer HiFi' on
amixer -c 0 sset 'Line' 31
```

---

## 2. Arduino Nano Firmware

The Arduino Nano reads the DJ fader (analog) and capacitive touch sensor, sending data to the Pi over serial at 500,000 baud.

### Flash the Firmware

1. Connect the Arduino Nano via USB to your development machine
2. Open `arduino_nano/arduino_nano.ino` in the Arduino IDE
3. Select board: **Arduino Nano** (ATmega328P, Old Bootloader for CH340 clones)
4. Select port: `/dev/ttyUSB0` (or equivalent)
5. Upload

### Serial Protocol (MK2)

The Arduino sends 7-byte packets at ~500 Hz:

| Byte | Content |
|---|---|
| 0 | `0xAA` sync byte |
| 1 | Fader high byte |
| 2 | Fader low byte |
| 3 | Capacitive touch high byte |
| 4 | Capacitive touch low byte |
| 5 | Buttons (4-bit bitfield, one bit per cue button) |
| 6 | Checksum (XOR of bytes 1-5) |

### Capacitive Touch Circuit

```
Arduino D10 ---- 1.2k ohm ---- Arduino D12 ---- wire ---- spring contact
                                                               |
                                                         copper slip ring
                                                               |
                                                         HDD platter
```

The `CapacitiveSensor` library measures charge time. When a finger touches the metal platter, body capacitance increases the reading.

---

## 3. Wiring

### I2C (MT6701 Encoder)

| MT6701 Pin | Pi Pin |
|---|---|
| VCC | 3.3V |
| GND | GND |
| SDA | GPIO 2 (SDA1) |
| SCL | GPIO 3 (SCL1) |

Verify with: `i2cdetect -y 1` -- should show `06` at address 0x06.

### SPI (ST7789 TFT Display)

| TFT Pin | Pi Pin |
|---|---|
| VCC | 3.3V |
| GND | GND |
| SCL | GPIO 11 (SPI0_SCLK) |
| SDA | GPIO 10 (SPI0_MOSI) |
| DC | GPIO 24 |
| RST | GPIO 25 |
| CS | GPIO 8 (SPI0_CE0) |
| BLK | 3.3V (or GPIO for dimming) |

### EC11 Rotary Encoder (Menu Navigation)

| Encoder Pin | Pi Pin |
|---|---|
| CLK | GPIO 23 |
| DT | GPIO 22 |
| SW | GPIO 27 |
| GND | GND |

### Buttons

| Button | Pin | Color |
|---|---|---|
| KB0 (select/confirm) | Pi GPIO 17 | -- |
| Cue 1 | Arduino A0 | Red |
| Cue 2 | Arduino A1 | Green |
| Cue 3 | Arduino A2 | Yellow |
| Cue 4 | Arduino A3 | Blue |

KB0 is active-low with internal pull-up on the Pi. Cue buttons are active-low with internal pull-ups on the Arduino, sent to the Pi as a 4-bit bitfield in the serial packet.

### Arduino Nano (USB Serial)

Connect the Arduino Nano to a Pi USB port with a USB cable. It appears as `/dev/ttyUSB0` (CH340 chip). No GPIO wiring or level shifters needed.

---

## 4. Build the Software

```bash
# Clone the repository
git clone https://github.com/no3z/ScratchTJ.git
cd ScratchTJ/software

# Build
make -j4

# The binary is ./xwax
```

### Run

```bash
sudo LC_ALL=en_GB.utf8 nice -n -19 ./xwax
```

- `sudo` -- required for direct GPIO/SPI/I2C access
- `LC_ALL=en_GB.utf8` -- required locale setting (xwax fails without it)
- `nice -n -19` -- real-time priority for audio performance

### Music Files

Place audio files in directories. Use the Deck menu to navigate and load tracks.

**Supported formats:** MP3, FLAC, WAV, OGG (handled by `xwax-import`).

**Recommended format:** 44100 Hz, 16-bit, stereo WAV with a standard 44-byte header. Files in this format load instantly via raw `dd` with zero CPU overhead. Other formats are decoded through `ffmpeg` or `mpg123` at load time.

**Converting audio for optimal performance:**

```bash
# Convert MP3 to compatible WAV (strips metadata for clean 44-byte header)
ffmpeg -y -i input.mp3 -map 0:a -ar 44100 -ac 2 \
  -acodec pcm_s16le -bitexact -map_metadata -1 output.wav

# Convert mono WAV to stereo
ffmpeg -y -i mono.wav -ar 44100 -ac 2 \
  -acodec pcm_s16le -bitexact -map_metadata -1 stereo.wav
```

**Important:** WAV files with embedded metadata (ID3 tags, cover art) have headers larger than 44 bytes. The `dd skip=44` fast path in `xwax-import` will produce noise for these files. Always use `-bitexact -map_metadata -1` when converting with ffmpeg.

### File Organization

```
~/samples/           # Scratch samples (Deck 1)
~/beats/             # Beat loops (Deck 0)
```

---

## 5. Configuration

Edit `scsettings.txt` in the software directory, or use the on-device Controller menu.

### Key Parameters

| Parameter | Default | Range | Description |
|---|---|---|---|
| `platterspeed` | 9100 | 1 - 32768 | Encoder-to-audio position ratio |
| `brakespeed` | 3000 | 1 - 10000 | Stop button deceleration rate |
| `slippiness` | 200 | 1 - 3000 | Slipmat simulation feel |
| `target_pitch` | 40 | 1 - 240 | Position tracking gain |
| `blipthreshold` | 400 | 50 - 2048 | Encoder glitch rejection threshold |
| `pitch_filter` | 0.1 | 0.01 - 1.0 | Pitch low-pass filter |
| `Fad Factor` | 0.1 | 0.01 - 10 | Fader curve transition point |
| `Fad Power` | 0.2 | 0.01 - 10 | Fader curve exponent |
| `fader_sharp` | 1.0 | 0 - 1.0 | Fader sharpness |
| `platterenabled` | 1 | 0 - 1 | Enable/disable platter |

### Presets

The 3-slot preset system saves all shared variables to files:
- `preset_1.cfg` through `preset_3.cfg`
- Save/load through the Presets menu (not yet wired into main menu flow)
- Last-used preset is auto-loaded on startup

---

## 6. Development Workflow

### Remote Sync & Build

From your development machine:

```bash
# Sync source files to Pi
rsync -avz --exclude='.git' --exclude='*.o' \
  software/ pi@192.168.1.88:~/ScratchTJ/software/

# Build on Pi
ssh pi@192.168.1.88 "cd ~/ScratchTJ/software && make -j4 2>&1"
```

### Useful Commands

```bash
# Check I2C devices
i2cdetect -y 1

# Read MT6701 angle (raw)
i2cget -y 1 0x06 0x03 w

# Monitor serial from Arduino
stty -F /dev/ttyUSB0 500000 raw
cat /dev/ttyUSB0 | xxd

# Test TFT display
cd software && make test_tft_ui && sudo ./test_tft_ui
```

---

## Troubleshooting

| Problem | Solution |
|---|---|
| "Could not honour the local encoding" | Set `LC_ALL=en_GB.utf8` before running |
| No sound output | Check `amixer` settings, verify AudioInjector overlay |
| TFT blank | Check SPI enabled, verify wiring (DC/RST pins) |
| Encoder not detected | Run `i2cdetect -y 1`, check I2C enabled |
| Arduino not communicating | Check `/dev/ttyUSB0` exists, verify baud rate 500000 |
| Platter not responding | Check `platterenabled=1` in scsettings.txt |
| Buttons not working | Check GPIO pin mapping in scsettings.txt |
| Permission denied | Run with `sudo` |
| WAV sounds like noise | WAV has metadata making header >44 bytes. Re-encode with `ffmpeg -bitexact -map_metadata -1` |
| Mono WAV plays at double speed | xwax expects stereo. Convert with `ffmpeg -ac 2` |
| Recording fails (device busy) | Peak meter may hold ALSA capture open. Update to latest `deck_menu.c` with `close_input_peak_monitor()` fix |

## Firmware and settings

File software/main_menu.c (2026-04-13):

#include <stdio.h>
#include <string.h>
#include <math.h>
#include <time.h>
#include "lcd_menu.h"
#include "main_menu.h"
#include "deck_menu.h"
#include "controller_menu.h"
#include "info_menu.h"
#include "player.h"
#include "track.h"
#include "cues.h"
#include "sc_input.h"
#include "shared_variables.h"
#include "deck.h"

extern bool needsUpdate;
extern MainMenuState mainMenuState;

/* Dynamic menu labels — Deck 2 first */
static char menuLabelBuf[7][40];
static const char *mainMenuOptions[7];
static int selectedItem = 0;
static int menuSize = 7;

/* ── Function mode overlay state ──────────────────────────────── */
static unsigned long mode_overlay_start_time = 0;
#define MODE_OVERLAY_DURATION_MS 1500

/* ── Cue flash state ──────────────────────────────────────────── */
static int prev_cue_states[4] = {0, 0, 0, 0};
static unsigned long cue_flash_time = 0;
static int cue_flash_idx = -1;
static unsigned long cue_trigger_time[4] = {0, 0, 0, 0};

static unsigned long main_millis(void) {
    struct timespec ts;
    clock_gettime(CLOCK_MONOTONIC, &ts);
    return (unsigned long)(ts.tv_sec * 1000 + ts.tv_nsec / 1000000);
}

/* ── Helpers ───────────────────────────────────────────────────── */

static const char *get_track_filename(struct deck *d) {
    if (!d->player.track || !d->player.track->path)
        return "No track";
    const char *slash = strrchr(d->player.track->path, '/');
    return slash ? slash + 1 : d->player.track->path;
}

static double get_track_duration(struct deck *d) {
    if (!d->player.track || d->player.track->rate == 0)
        return 0.0;
    return (double)d->player.track->length / d->player.track->rate;
}

/* Build one deck label: "Dk2 > filename 1:23" */
static void build_deck_label(char *buf, int bufsize,
                             struct deck *d, int deck_num) {
    bool playing = player_is_active(&d->player);
    const char *fname = get_track_filename(d);

    if (d->player.track && d->player.track->path) {
        double elapsed = player_get_elapsed(&d->player);
        char t[16];
        oled_format_time(elapsed, t, sizeof(t));
        snprintf(buf, bufsize, "Dk%d %c %.10s %s",
                 deck_num, playing ? '>' : '=', fname, t);
    } else {
        snprintf(buf, bufsize, "Dk%d  No track", deck_num);
    }
}

/* Build main menu labels — Deck 2 first */
static void build_main_menu_labels(struct deck *decks[], int deck_count) {
    if (deck_count >= 2)
        build_deck_label(menuLabelBuf[0], sizeof(menuLabelBuf[0]),
                         decks[1], 2);
    if (deck_count >= 1)
        build_deck_label(menuLabelBuf[1], sizeof(menuLabelBuf[1]),
                         decks[0], 1);
    snprintf(menuLabelBuf[2], sizeof(menuLabelBuf[2]), "Randomize");
    snprintf(menuLabelBuf[3], sizeof(menuLabelBuf[3]), "Record Dk2");
    snprintf(menuLabelBuf[4], sizeof(menuLabelBuf[4]), "Btn: %s",
             current_function_mode == FUNC_MODE_SETTINGS ? "SETTINGS" : "CUE");
    snprintf(menuLabelBuf[5], sizeof(menuLabelBuf[5]), "Config");
    snprintf(menuLabelBuf[6], sizeof(menuLabelBuf[6]), "Info");
    for (int i = 0; i < 7; i++)
        mainMenuOptions[i] = menuLabelBuf[i];
}

/* ── Function mode display helpers ─────────────────────────────── */

static void draw_mode_overlay(void) {
    unsigned long now = main_millis();
    if (mode_overlay_start_time == 0) return;
    unsigned long elapsed = now - mode_overlay_start_time;
    if (elapsed >= MODE_OVERLAY_DURATION_MS) {
        mode_overlay_start_time = 0;
        return;
    }

    /* Dark box centered on platter area */
    oled_fill_rect(10, 70, 220, 70, RGB565(10, 10, 30));
    /* Border in deck accent color */
    uint16_t color = (active_deck == 1) ? THEME_DECK2_ACCENT : THEME_DECK1_ACCENT;
    oled_draw_line(10, 70, 229, 70, color);
    oled_draw_line(10, 139, 229, 139, color);

    /* Big label: DECK 1 or DECK 2 */
    char label[16];
    snprintf(label, sizeof(label), "DECK %d", active_deck + 1);
    int tw = st7789_string_width(label, FONT_LARGE);
    oled_text_color((DISPLAY_WIDTH - tw) / 2, 90, label, FONT_LARGE, color);

    /* Subtitle: button mode */
    const char *sub = (current_function_mode == FUNC_MODE_SETTINGS)
                      ? "Buttons: SETTINGS" : "Buttons: CUE";
    int sw = st7789_string_width(sub, FONT_SMALL);
    oled_text_color((DISPLAY_WIDTH - sw) / 2, 118, sub, FONT_SMALL,
                    RGB565(160, 160, 160));
}

static const char *settings_param_labels[4] = {
    "PITCH", "SPEED", "BEND", "VOLUME"
};
static const char *settings_param_names[4] = {
    NULL, "platterspeed", NULL, NULL
};

static void draw_settings_value_overlay(struct deck *d2) {
    if (current_function_mode != FUNC_MODE_SETTINGS || settings_buttons_held == 0)
        return;

    /* Find first held button */
    int btn = -1;
    for (int i = 0; i < 4; i++) {
        if (settings_buttons_held & (1 << i)) { btn = i; break; }
    }
    if (btn < 0) return;

    /* Get current value */
    float val = 0;
    if (btn == 0) {
        val = (float)d2->player.note_pitch;
    } else if (btn == 2) {
        val = (float)d2->player.fader_pitch;  /* bend ±8% */
    } else if (btn == 3) {
        val = (float)d2->player.setVolume;  /* gain multiplier */
    } else if (settings_param_names[btn]) {
        get_variable_value(settings_param_names[btn], &val);
    }

    /* Dark overlay on platter area */
    oled_fill_rect(10, 40, 125, 80, RGB565(5, 5, 20));

    /* Parameter name */
    uint16_t accent = RGB565(0, 180, 255);
    oled_text_color(18, 48, settings_param_labels[btn], FONT_MEDIUM, accent);

    /* Large value */
    char vbuf[16];
    if (btn == 0) snprintf(vbuf, sizeof(vbuf), "%.3f", val);                 /* pitch */
    else if (btn == 1) snprintf(vbuf, sizeof(vbuf), "%.0f", val);             /* platterspeed */
    else if (btn == 2) snprintf(vbuf, sizeof(vbuf), "%+.1f%%", (val - 1.0f) * 100.0f); /* bend % */
    else if (btn == 3) snprintf(vbuf, sizeof(vbuf), "x%.2f", val);            /* gain */
    else snprintf(vbuf, sizeof(vbuf), "%.1f", val);
    oled_text_color(18, 72, vbuf, FONT_LARGE, COLOR_WHITE);

    /* Visual gauge bar */
    float norm = 0;
    if (btn == 0) norm = (val - 0.25f) / 3.75f;          /* note_pitch 0.25-4.0 */
    else if (btn == 1) norm = val / 32768.0f;             /* platterspeed */
    else if (btn == 2) norm = (val - 0.92f) / 0.16f;      /* bend 0.92-1.08 (centered ±8%) */
    else if (btn == 3) norm = val / 8.0f;                 /* gain (max 8x with soft-clip) */
    if (norm < 0) norm = 0;
    if (norm > 1) norm = 1;
    oled_draw_progress_bar(18, 100, 110, 6, norm, accent);
}

static void draw_function_mode_strip(int y) {
    uint16_t bg = RGB565(15, 10, 30);
    oled_fill_rect(0, y, DISPLAY_WIDTH, 14, bg);

    if (current_function_mode == FUNC_MODE_CUE) {
        oled_fill_rect(0, y, 3, 14, RGB565(255, 200, 0));
        oled_text_color(6, y + 3, "CUE", FONT_SMALL, RGB565(255, 200, 0));
        oled_text_color(32, y + 3, "1:J/S 2:J/S 3:J/S 4:J/S", FONT_SMALL,
                        RGB565(120, 120, 120));
    } else {
        oled_fill_rect(0, y, 3, 14, RGB565(0, 180, 255));
        oled_text_color(6, y + 3, "SET", FONT_SMALL, RGB565(0, 180, 255));
        /* Color-coded button labels */
        oled_text_color(32, y + 3, "1:", FONT_SMALL, THEME_CUE1_COLOR);
        oled_text_color(48, y + 3, "Pit", FONT_SMALL, RGB565(160, 160, 160));
        oled_text_color(76, y + 3, "2:", FONT_SMALL, THEME_CUE2_COLOR);
        oled_text_color(92, y + 3, "Spd", FONT_SMALL, RGB565(160, 160, 160));
        oled_text_color(120, y + 3, "3:", FONT_SMALL, THEME_CUE3_COLOR);
        oled_text_color(136, y + 3, "S/S", FONT_SMALL, RGB565(160, 160, 160));
        oled_text_color(168, y + 3, "4:", FONT_SMALL, THEME_CUE4_COLOR);
        oled_text_color(184, y + 3, "Vol", FONT_SMALL, RGB565(160, 160, 160));
    }
}

/* ── Home Screen — Deck 2 focused ─────────────────────────────── */

static void draw_platter(struct deck *d, int cx, int cy, int r,
                         uint16_t accent) {
    /* ── Fader arc: ring fills CW from 12 o'clock proportional to faderVolume ── */
    float fvol = d->player.faderVolume;
    if (fvol < 0.0f) fvol = 0.0f;
    if (fvol > 1.0f) fvol = 1.0f;

    /* Always draw dim base ring */
    oled_draw_circle(cx, cy, r, RGB565(40, 40, 40));
    oled_draw_circle(cx, cy, r - 1, RGB565(40, 40, 40));

    if (fvol > 0.01f) {
        /* Draw lit arc from -90° (top) CW for fvol*360° */
        float arc_deg = fvol * 360.0f;
        int steps = (int)(arc_deg * 0.5f); /* ~2 pixels per degree */
        if (steps < 1) steps = 1;
        for (int s = 0; s <= steps; s++) {
            float deg = -90.0f + (arc_deg * s / steps);
            float rad = deg * (float)M_PI / 180.0f;
            float cs = cosf(rad), sn = sinf(rad);
            /* Draw 3px thick arc */
            for (int rr = r - 2; rr <= r; rr++) {
                int px = cx + (int)(rr * cs);
                int py = cy + (int)(rr * sn);
                if (px >= 0 && px < 240 && py >= 0 && py < 240)
                    st7789_pixel(px, py, accent);
            }
        }
    }

    /* Touch: extra bright inner glow ring */
    if (capIsTouched) {
        oled_draw_circle(cx, cy, r - 3, accent);
    }

    /* 12 tick marks around the platter */
    for (int t = 0; t < 12; t++) {
        float tick_rad = (t * 30.0f - 90.0f) * (float)M_PI / 180.0f;
        int tick_inner = r - 8;
        int tick_outer = r - 3;
        if (t % 3 == 0) tick_inner = r - 12;
        int tx1 = cx + (int)(tick_inner * cosf(tick_rad));
        int ty1 = cy + (int)(tick_inner * sinf(tick_rad));
        int tx2 = cx + (int)(tick_outer * cosf(tick_rad));
        int ty2 = cy + (int)(tick_outer * sinf(tick_rad));
        uint16_t tick_color = (t % 3 == 0) ? RGB565(140, 140, 140) : RGB565(80, 80, 80);
        oled_draw_line(tx1, ty1, tx2, ty2, tick_color);
    }

    /* Inner hub */
    int hub_r = r / 4;
    oled_draw_circle(cx, cy, hub_r, RGB565(60, 60, 60));

    int needle_inner = hub_r + 2;
    int needle_outer = r - 3;

    /* ── Ghost needle (audio position) — drawn first, underneath ── */
    float ps = 1.0f;
    get_variable_value("platterspeed", &ps);
    double ghost_raw = d->player.position * (double)ps;
    int ghost_angle = ((int)fmod(ghost_raw, 16384.0) + 16384) % 16384;
    float ghost_deg = (ghost_angle * 360.0f) / 16384.0f;
    float ghost_rad = (ghost_deg - 90.0f) * (float)M_PI / 180.0f;
    int gx1 = cx + (int)(needle_inner * cosf(ghost_rad));
    int gy1 = cy + (int)(needle_inner * sinf(ghost_rad));
    int gx2 = cx + (int)(needle_outer * cosf(ghost_rad));
    int gy2 = cy + (int)(needle_outer * sinf(ghost_rad));
    /* 2px thick: draw center line + 1px perpendicular offset */
    oled_draw_line(gx1, gy1, gx2, gy2, THEME_DECK2_ACCENT_DIM);
    float perp_rad = ghost_rad + (float)M_PI / 2.0f;
    int offx = (int)roundf(cosf(perp_rad));
    int offy = (int)roundf(sinf(perp_rad));
    oled_draw_line(gx1 + offx, gy1 + offy, gx2 + offx, gy2 + offy, THEME_DECK2_ACCENT_DIM);

    /* ── Physical needle (encoder position) — drawn on top ── */
    float phys_deg = (d->encoderAngle * 360.0f) / 16384.0f;
    float phys_rad = (phys_deg - 90.0f) * (float)M_PI / 180.0f;
    int px1 = cx + (int)(needle_inner * cosf(phys_rad));
    int py1 = cy + (int)(needle_inner * sinf(phys_rad));
    int px2 = cx + (int)(needle_outer * cosf(phys_rad));
    int py2 = cy + (int)(needle_outer * sinf(phys_rad));
    oled_draw_line(px1, py1, px2, py2, accent);

    /* Elapsed time in center of hub (loop-aware) */
    double hub_duration = get_track_duration(d);
    double hub_elapsed_raw = d->player.track ? player_get_elapsed(&d->player) : 0.0;
    double hub_elapsed = (hub_duration > 0) ? fmod(hub_elapsed_raw, hub_duration) : hub_elapsed_raw;
    char tbuf[16];
    oled_format_time(hub_elapsed, tbuf, sizeof(tbuf));
    int tw = st7789_string_width(tbuf, FONT_SMALL);
    oled_text_color(cx - tw / 2, cy - 5, tbuf, FONT_SMALL, THEME_TEXT);
}

static void draw_deck_compact(struct deck *d, int deck_num,
                              uint16_t accent, int y) {
    char buf[40];
    bool playing = player_is_active(&d->player);

    /* Accent stripe + title */
    oled_fill_rect(0, y, DISPLAY_WIDTH, 18, RGB565(0, 20, 40));
    oled_fill_rect(0, y, 3, 18, accent);

    snprintf(buf, sizeof(buf), "Dk%d", deck_num);
    oled_text_color(6, y + 2, buf, FONT_SMALL, accent);
    oled_text_color(30, y + 2, playing ? ">" : "=", FONT_SMALL,
                    playing ? THEME_PLAYING : THEME_STOPPED);
    oled_text_color(42, y + 2, get_track_filename(d), FONT_SMALL, THEME_TEXT);

    /* Time right-aligned (loop-aware) */
    double compact_duration = get_track_duration(d);
    double compact_elapsed_raw = d->player.track ? player_get_elapsed(&d->player) : 0.0;
    double compact_elapsed = (compact_duration > 0) ? fmod(compact_elapsed_raw, compact_duration) : compact_elapsed_raw;
    char t[8];
    oled_format_time(compact_elapsed, t, sizeof(t));
    int tw = st7789_string_width(t, FONT_SMALL);
    oled_text_color(DISPLAY_WIDTH - tw - 4, y + 2, t, FONT_SMALL, THEME_TEXT);

    /* Mini progress bar below */
    float progress = (compact_duration > 0) ? (float)(compact_elapsed / compact_duration) : 0.0f;
    oled_draw_progress_bar(6, y + 14, DISPLAY_WIDTH - 12, 3, progress, accent);
}

void display_home_screen(struct deck *decks[], int deck_count) {
    oled_clear();

    if (deck_count < 2) return;

    int ad = active_deck;
    int other = 1 - ad;
    struct deck *d_hero = decks[ad];
    struct deck *d_other = decks[other];
    uint16_t hero_accent = (ad == 1) ? THEME_DECK2_ACCENT : THEME_DECK1_ACCENT;
    uint16_t other_accent = (ad == 1) ? THEME_DECK1_ACCENT : THEME_DECK2_ACCENT;
    char buf[40];
    bool playing = player_is_active(&d_hero->player);

    /* ── Compact title bar (y=0..16) ─────────────────────────── */
    oled_fill_rect(0, 0, DISPLAY_WIDTH, 16, RGB565(0, 20, 40));
    oled_fill_rect(0, 0, 4, 16, hero_accent);

    snprintf(buf, sizeof(buf), "Dk%d %c %.16s",
             ad + 1, playing ? '>' : '=', get_track_filename(d_hero));
    oled_text_color(8, 2, buf, FONT_SMALL, THEME_TEXT);

    snprintf(buf, sizeof(buf), "%.2fx", d_hero->player.pitch);
    int pw = st7789_string_width(buf, FONT_SMALL);
    oled_text_color(DISPLAY_WIDTH - pw - 4, 2, buf, FONT_SMALL,
                    hero_accent);

    /* ── Mode indicator in title bar ─────────────────────────── */
    if (current_function_mode == FUNC_MODE_SETTINGS) {
        oled_fill_rect(DISPLAY_WIDTH - pw - 18, 4, 10, 8, RGB565(0, 180, 255));
        oled_text_color(DISPLAY_WIDTH - pw - 17, 4, "S", FONT_SMALL, COLOR_WHITE);
    }

    /* ── Large platter shifted left (y=18..148, cx=76, r=58) ── */
    draw_platter(d_hero, 76, 83, 58, hero_accent);

    /* ── Info column right of platter (x=145..236) ───────────── */
    {
        /* Text labels first */
        uint16_t dim = RGB565(160, 160, 160);
        float ps_val = 1.0f;
        get_variable_value("platterspeed", &ps_val);
        snprintf(buf, sizeof(buf), "Spd: %d", (int)ps_val);
        oled_text_color(145, 24, buf, FONT_SMALL, dim);

        snprintf(buf, sizeof(buf), "Pitch: %.2fx", d_hero->player.pitch);
        oled_text_color(145, 38, buf, FONT_SMALL, dim);

        snprintf(buf, sizeof(buf), "Motor: %.2f", d_hero->player.motor_speed);
        oled_text_color(145, 52, buf, FONT_SMALL, dim);

        float slip_val = 200.0f;
        get_variable_value("slippiness", &slip_val);
        snprintf(buf, sizeof(buf), "Slip: %.0f", slip_val);
        oled_text_color(145, 66, buf, FONT_SMALL, dim);

        /* ── Fader history graph below text (right of platter) ─── */
        #define FHIST_LEN 90
        #define FHIST_X   145
        #define FHIST_Y   82
        #define FHIST_H   55
        /* Auto-zoom: find max value in history buffer and scale to fill graph */
        static float fader_history[FHIST_LEN] = {0};
        static int fhist_idx = 0;

        /* Push 1 sample per display frame → smooth 1px/frame scroll.
         * Visible window = FHIST_LEN * HOME_REDRAW_INTERVAL_MS (~2sec at 22ms) */
        fader_history[fhist_idx] = d_hero->player.faderVolume;
        fhist_idx = (fhist_idx + 1) % FHIST_LEN;

        /* Auto-zoom: find peak in history, scale so peak fills ~90% of graph */
        float hist_max = 0.001f;
        for (int i = 0; i < FHIST_LEN; i++) {
            if (fader_history[i] > hist_max) hist_max = fader_history[i];
        }
        float auto_zoom = 0.9f / hist_max;
        if (auto_zoom > 50.0f) auto_zoom = 50.0f;  /* cap zoom when silent */
        if (auto_zoom < 1.0f) auto_zoom = 1.0f;

        /* Baseline dim line */
        oled_draw_line(FHIST_X, FHIST_Y + FHIST_H, FHIST_X + FHIST_LEN,
                       FHIST_Y + FHIST_H, RGB565(30, 30, 30));

        /* Draw scrolling history: oldest left, newest right */
        for (int i = 0; i < FHIST_LEN - 1; i++) {
            int si  = (fhist_idx + i) % FHIST_LEN;
            int si2 = (fhist_idx + i + 1) % FHIST_LEN;
            float v1 = fader_history[si] * auto_zoom;
            float v2 = fader_history[si2] * auto_zoom;
            if (v1 > 1.0f) v1 = 1.0f;
            if (v2 > 1.0f) v2 = 1.0f;
            int x1 = FHIST_X + i;
            int x2 = FHIST_X + i + 1;
            int y1 = FHIST_Y + FHIST_H - (int)(v1 * FHIST_H);
            int y2 = FHIST_Y + FHIST_H - (int)(v2 * FHIST_H);

            /* Bright fade: older = dimmer, newest = full accent */
            int age = (FHIST_LEN - 1 - i);
            int r_c = 255 - age * 2; if (r_c < 40) r_c = 40;
            int g_c = 140 - age;     if (g_c < 20) g_c = 20;
            oled_draw_line(x1, y1, x2, y2, RGB565(r_c, g_c, 0));

            /* Fill below the line for a solid waveform look */
            if (v1 > 0.01f) {
                int fill_bright = 60 - age / 2; if (fill_bright < 10) fill_bright = 10;
                for (int fy = y1 + 1; fy <= FHIST_Y + FHIST_H; fy++)
                    st7789_pixel(x1, fy, RGB565(fill_bright, fill_bright / 3, 0));
            }
        }
    }

    /* ── Full-width progress bar (y=150..156) — loop-aware ──── */
    double elapsed_raw = d_hero->player.track ? player_get_elapsed(&d_hero->player) : 0.0;
    double duration = get_track_duration(d_hero);
    double elapsed = (duration > 0) ? fmod(elapsed_raw, duration) : elapsed_raw;
    float progress = (duration > 0) ? (float)(elapsed / duration) : 0.0f;
    oled_draw_progress_bar(4, 150, 232, 6, progress, THEME_DECK2_ACCENT);

    /* ── Time + Fader row (y=160..172) ───────────────────────── */
    {
        double remain = duration - elapsed;
        if (remain < 0) remain = 0;

        char e[16], r[16];
        oled_format_time(elapsed, e, sizeof(e));
        oled_format_time(remain, r, sizeof(r));

        /* Elapsed left */
        oled_text_color(4, 160, e, FONT_SMALL, THEME_TEXT);

        /* Center fader */
        oled_draw_center_fader(60, 162, 120, 8,
                               (float)ADCs[0], RGB565(200, 200, 200));

        /* Remaining right */
        char rbuf[20];
        snprintf(rbuf, sizeof(rbuf), "-%s", r);
        int rw = st7789_string_width(rbuf, FONT_SMALL);
        oled_text_color(DISPLAY_WIDTH - rw - 4, 160, rbuf, FONT_SMALL,
                        remain < 30.0 ? RGB565(255, 80, 80) : RGB565(130, 130, 130));
    }

    /* ── Other deck compact strip (y=176..194) ─────────────── */
    draw_deck_compact(d_other, other + 1, other_accent, 176);

    /* ── Function mode info strip (y=196..210) ────────────────── */
    draw_function_mode_strip(196);

    /* ── Cue flash logic (y=212, moved from 198) ──────────────── */
    {
        unsigned long now = main_millis();
        for (int i = 0; i < 4; i++) {
            if (cue_display_states[i] == CUE_STATE_SET &&
                prev_cue_states[i] != CUE_STATE_SET) {
                cue_flash_idx = i;
                cue_flash_time = now;
            }
            if (cue_display_states[i] == CUE_STATE_ACTIVE &&
                prev_cue_states[i] != CUE_STATE_ACTIVE) {
                cue_trigger_time[i] = now;
            }
            if (cue_display_states[i] == CUE_STATE_ACTIVE &&
                cue_trigger_time[i] > 0 &&
                (now - cue_trigger_time[i]) >= 300) {
                cue_display_states[i] = CUE_STATE_SET;
                cue_trigger_time[i] = 0;
            }
            prev_cue_states[i] = cue_display_states[i];
        }
        if (cue_flash_idx >= 0 && (now - cue_flash_time) < 500) {
            snprintf(buf, sizeof(buf), "CUE %d SET", cue_flash_idx + 1);
            int bw = st7789_string_width(buf, FONT_MEDIUM);
            oled_text_color((DISPLAY_WIDTH - bw) / 2, 212, buf, FONT_MEDIUM,
                            THEME_CUE_SET);
        } else {
            cue_flash_idx = -1;
        }
    }

    /* ── Settings value overlay (on top of platter when adjusting) ── */
    draw_settings_value_overlay(d_hero);

    /* ── Mode overlay (big temporal label, drawn last) ──────────── */
    draw_mode_overlay();

    /* Cue bar drawn by overlay in oled_flush() at y=220 */
    oled_flush();
}

/* ── Display dispatch ──────────────────────────────────────────── */
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

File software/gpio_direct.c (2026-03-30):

#include "gpio_direct.h"
#include <stdio.h>
#include <stdlib.h>
#include <fcntl.h>
#include <unistd.h>
#include <sys/mman.h>
#include <time.h>

/* BCM2836 GPIO registers (Pi 2/3) */
#define GPIO_BASE   0x3F200000
#define GPIO_LEN    0x100
#define GPFSEL0     0
#define GPSET0      7
#define GPCLR0      10
#define GPLEV0      13
#define GPPUD       37
#define GPPUDCLK0   38

static volatile uint32_t *gpio_reg;
static struct timespec start_time;

int gpio_direct_init(void)
{
    int fd = open("/dev/mem", O_RDWR | O_SYNC);
    if (fd < 0) {
        perror("gpio_direct: open /dev/mem");
        return -1;
    }
    gpio_reg = mmap(NULL, GPIO_LEN, PROT_READ | PROT_WRITE,
                    MAP_SHARED, fd, GPIO_BASE);
    close(fd);
    if (gpio_reg == MAP_FAILED) {
        perror("gpio_direct: mmap");
        return -1;
    }

    clock_gettime(CLOCK_MONOTONIC, &start_time);
    return 0;
}

void gpio_set_input(int pin)
{
    int reg = pin / 10, shift = (pin % 10) * 3;
    gpio_reg[reg] &= ~(7 << shift);
}

void gpio_set_output(int pin)
{
    int reg = pin / 10, shift = (pin % 10) * 3;
    gpio_reg[reg] &= ~(7 << shift);
    gpio_reg[reg] |= (1 << shift);
}

int gpio_read(int pin)
{
    return (gpio_reg[GPLEV0] >> pin) & 1;
}

void gpio_write(int pin, int value)
{
    if (value)
        gpio_reg[GPSET0] = 1u << pin;
    else
        gpio_reg[GPCLR0] = 1u << pin;
}

void gpio_set_pullup(int pin)
{
    gpio_reg[GPPUD] = 2;  /* pull-up */
    usleep(10);
    gpio_reg[GPPUDCLK0] = 1u << pin;
    usleep(10);
    gpio_reg[GPPUD] = 0;
    gpio_reg[GPPUDCLK0] = 0;
}

unsigned long gpio_millis(void)
{
    struct timespec now;
    clock_gettime(CLOCK_MONOTONIC, &now);
    return (unsigned long)((now.tv_sec - start_time.tv_sec) * 1000 +
                           (now.tv_nsec - start_time.tv_nsec) / 1000000);
}

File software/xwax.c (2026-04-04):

/*
 * Copyright (C) 2018 Mark Hills <mark@xwax.org>
 *
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
 */

#include <assert.h>
#include <locale.h>
#include <stdio.h>
#include <stdlib.h>
#include <string.h>
#include <unistd.h>
#include <sys/mman.h> /* mlockall() */

#include <unistd.h>		   //Needed for I2C port
#include <fcntl.h>		   //Needed for I2C port
#include <sys/ioctl.h>	   //Needed for I2C port
#include <linux/i2c-dev.h> //Needed for I2C port
#include <time.h>
#include <dirent.h>
#include <stdint.h>
#include <string.h>
#include <signal.h>

#include "alsa.h"
#include "controller.h"
#include "device.h"
#include "dummy.h"
#include "realtime.h"
#include "thread.h"
#include "rig.h"
#include "track.h"
#include "xwax.h"
#include "sc_input.h"
#include "sc_midimap.h"
#include "dicer.h"
#include "lcd_menu.h"
#include "shared_variables.h"

#define DEFAULT_IMPORTER EXECDIR "/xwax-import"

struct deck deck[2];
struct deck *decks[] = { &deck[0], &deck[1] };
struct rt rt;

static const char *importer;

SC_SETTINGS scsettings;

struct mapping *maps = NULL;

/* Editable variables (registered with shared_variables system) */
float input_curveFactor = 0.1f;
float input_curvePower = 0.2f;
float input_curveSwitch = 1.0f;
float slippiness = 200.f;
float brakespeed = 3000.f;
float platterspeed = 9100.0f;
float target_pitch = 40.0f;
float blipthreshold = 400.0f;
float pitch_filter = 0.1f;
float fader_sharpness = 1.0f;
float fhist_secs = 2.0f;

unsigned int countChars(char *string, char c)
{
	unsigned int count = 0;
	
	//printf("Checking for commas in %s\n", string);

	do
	{
		if ((*string) == c)
		{
			count++;
		}
	} while ((*(string++)));
	return count;
}

void loadSettings()
{
	FILE *fp;
	char *line = NULL;
	size_t len = 0;
	ssize_t read;
	char *param, *actions;
	char *value;
	unsigned char channel = 0, notenum = 0, controlType = 0, pin = 0, pullup = 0, port = 0;
	char edge;
	char delim[] = "=";
	char delimc[] = ",";
	unsigned char midicommand[3];
	char *linetok, *valuetok;
	// set defaults
	scsettings.buffersize = 256;
	scsettings.faderclosepoint = 2;
	scsettings.faderopenpoint = 10;
	scsettings.platterenabled = 1;
	scsettings.platterspeed = 9100;
	scsettings.samplerate = 48000;
	scsettings.updaterate = 2000;
	scsettings.debouncetime = 5;
	scsettings.holdtime = 100;
	scsettings.slippiness = 200;
	scsettings.brakespeed = 3000;
	scsettings.pitchrange = 50;
	scsettings.mididelay = 5;
	scsettings.volAmount = 0.03;
	scsettings.volAmountHeld = 0.001;
	scsettings.initialVolume = 0.125;
	scsettings.midiRemapped = 0;
	scsettings.ioRemapped = 0;
	scsettings.jogReverse = 1;
	scsettings.cutbeats = 0;

	// later we'll check for sc500 pin and use it to set following settings
	scsettings.disablevolumeadc = 0;
	scsettings.disablepicbuttons = 0;

	// Load any settings from config file
	fp = fopen("/media/sda/scsettings.txt", "r");
	if (fp == NULL)
	{
		// load internal copy instead
		fp = fopen("/home/no3z/ScratchTJ/software/scsettings.txt", "r");
	}


	if (fp != NULL)
	{
		while ((read = getline(&line, &len, fp)) != -1)
		{
			if (strlen(line) < 2 || line[0] == '#')
			{ // Comment or blank line
			}
			else
			{
				param = strtok_r(line, delim, &linetok);
				value = strtok_r(NULL, delim, &linetok);

				if (strcmp(param, "buffersize") == 0)
					scsettings.buffersize = atoi(value);
				else if (strcmp(param, "faderclosepoint") == 0)
					scsettings.faderclosepoint = atoi(value);
				else if (strcmp(param, "faderopenpoint") == 0)
					scsettings.faderopenpoint = atoi(value);
				else if (strcmp(param, "platterenabled") == 0)
					scsettings.platterenabled = atoi(value);
				else if (strcmp(param, "disablevolumeadc") == 0)
					scsettings.disablevolumeadc = atoi(value);
				else if (strcmp(param, "platterspeed") == 0)
					scsettings.platterspeed = atoi(value);
				else if (strcmp(param, "samplerate") == 0)
					scsettings.samplerate = atoi(value);
				else if (strcmp(param, "updaterate") == 0)
					scsettings.updaterate = atoi(value);
				else if (strcmp(param, "debouncetime") == 0)
					scsettings.debouncetime = atoi(value);
				else if (strcmp(param, "holdtime") == 0)
					scsettings.holdtime = atoi(value);
				else if (strcmp(param, "slippiness") == 0)
					scsettings.slippiness = atoi(value);
				else if (strcmp(param, "brakespeed") == 0)
					scsettings.brakespeed = atoi(value);
				else if (strcmp(param, "pitchrange") == 0)    
					scsettings.pitchrange = atoi(value);
				else if (strcmp(param, "jogreverse") == 0)
					scsettings.jogReverse = atoi(value);
				else if (strcmp(param, "cutbeats") == 0)
					scsettings.cutbeats = atoi(value);
				else if (strstr(param, "midii") != NULL)
				{
					scsettings.midiRemapped = 1;
					controlType = atoi(strtok_r(value, delimc, &valuetok));
					channel = atoi(strtok_r(NULL, delimc, &valuetok));
					notenum = atoi(strtok_r(NULL, delimc, &valuetok));
					edge = atoi(strtok_r(NULL, delimc, &valuetok));
					actions = strtok_r(NULL, delimc, &valuetok);

					//255 means bind to all notes
					if (notenum == 255){

						// Build MIDI command
						midicommand[0] = (controlType << 4) | channel;
						midicommand[1] = notenum;
						midicommand[2] = 0;

						char tempact[20];
						for (midicommand[1] = 0; midicommand[1] < 128; midicommand[1]++){
							sprintf(tempact, "%s%u", actions, midicommand[1]);
							add_config_mapping(
								&maps,
								MAP_MIDI,
								midicommand,
								0,
								0,
								0,
								edge,
								tempact);
						}
					}
					// otherwise just bind to one note
					else {
						// Build MIDI command
						midicommand[0] = (controlType << 4) | channel;
						midicommand[1] = notenum;
						midicommand[2] = 0;
						add_config_mapping(
							&maps,
							MAP_MIDI,
							midicommand,
							0,
							0,
							0,
							edge,
							actions);
					}
				}
				else if (strstr(param, "io") != NULL)
				{
					scsettings.ioRemapped = 1;
					unsigned int commaCount = countChars(value, ',');
					//printf("Found io %s - comacount %d\n", value, commaCount);
					port = 0;
					if (commaCount == 4){
						port = atoi(strtok_r(value, delimc, &valuetok));
						pin = atoi(strtok_r(NULL, delimc, &valuetok));
					}
					else {
						pin = atoi(strtok_r(value, delimc, &valuetok));
					}
					pullup = atoi(strtok_r(NULL, delimc, &valuetok));
					edge = atoi(strtok_r(NULL, delimc, &valuetok));
					actions = strtok_r(NULL, delimc, &valuetok);
					add_config_mapping(
						&maps,
						MAP_IO,
						NULL,
						port,
						pin,
						pullup,
						edge,
						actions);
				}
				else if (strcmp(param, "mididelay") == 0) // Literally just a sleep to allow USB devices longer to initialize
					scsettings.mididelay = atoi(value);
				else
				{
					printf("Unrecognised configuration line - Param : %s , value : %s\n", param, value);
				}
			}
		}
	}
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

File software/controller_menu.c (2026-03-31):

#include "controller_menu.h"
#include "lcd_menu.h"
#include "alsa_mixer.h"
#include <stdio.h>
#include <string.h>
#include <unistd.h>
#include <sys/stat.h>
#include "sc_input.h"
#include "xwax.h"
#include "shared_variables.h"
#include "oled_display.h"

/* Constants */
#define MAX_MIXER_CONTROLS 20

/* Globals */
extern bool needsUpdate;
extern MainMenuState mainMenuState;

static ControllerMenuOption selectedOption = CONTROLLER_SOUND_SETTINGS;
static MixerControl mixerControls[MAX_MIXER_CONTROLS];
static int mixerControlCount = 0;

/* Config save path */
#define CONFIG_SAVE_PATH "/home/no3z/.scratchtj/config.cfg"

/* Controller menu options */
static const char *controllerOptions[] = {
    "Sound Settings",
    "Global Settings",
    "Save Config",
    "Reset Defaults"
};

/* Forward declarations */
static void adjust_mixer_control(int selectedIndex);
static void adjust_variable_value(EditableVariable *variable);
static void display_mixer_control(MixerControl *control);
static void action_save_config(void);
static void action_reset_defaults(void);

/* Display Controller Menu */
void display_controller_menu(struct deck *d, int deck_no) {
    oled_clear();
    oled_draw_title_bar("Config");
    oled_draw_menu_list(controllerOptions, CONTROLLER_MENU_OPTION_COUNT,
                        selectedOption, 0, MENU_VISIBLE_LINES);
    oled_flush();
}

/* Handle Controller Menu Navigation */
void handle_controller_menu_navigation(struct deck *d, int deckno) {
    int encoder_movement = rotary_encoder_moved();
    int button_press = rotary_button_pressed();
    int kb0 = kb0_button_pressed();

    if (encoder_movement != 0) {
        selectedOption = (ControllerMenuOption)((selectedOption + encoder_movement +
                          CONTROLLER_MENU_OPTION_COUNT) % CONTROLLER_MENU_OPTION_COUNT);
        needsUpdate = true;
    }
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

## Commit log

2024-11-23 Fix discrepancy with target_pitch and new buffer_size
    [player.c, sc_input.c, xwax.c]
2024-11-24 LCD Menu fixes. Allow switch fader
    [controller_menu.c, deck_menu.c, main_menu.c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]
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2024-12-13 Fixes. Set double audio buffer at 128 period Enable update rate usleep
    [player.c, sc_input.c, xwax.c]
2025-01-26 New clamp_pitch and skip_pitch variables. Finally getting somewhere with the wobble
    [player.c, sc_input.c, xwax.c]
2025-01-30 Fix parameters for 128 buffer_size Fix recording, save wav header
    [deck_menu.c, sc_input.c, xwax.c]
2025-05-02 Add 2 buttons on GPIO 17 and 27 for short and long press
    [lcd_menu.c]
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2025-11-09 Fix backward scratch velocity and eliminate flutter
    This commit restores the original SC1000 pitch parameters to fix
    sluggish backward scratch response and audio flutter issues.
    Changes:
    - Increased target_pitch from 16.0 to 40.0 for proper scratch response
    (2.5x more responsive to hand movements)
    - Reduced pitch_mixer from 0.115 to 0.1 to match original smoothing
    - Increased clamp_pitch from 12.5 to 20.0 to allow full scratch range
    - Disabled skip_pitch (0.0 from 4.0) to eliminate flutter during
    directional changes
    These values now match the original rasteri/SC1000 implementation
    and should provide smooth, responsive scratching in both directions.
    [xwax.c]
2025-11-09 Increase audio buffer size to reduce flutter and improve stability
    This commit doubles the audio buffer size from 128 to 256 frames
    to match the original SC1000 configuration.
    - Updated default buffersize from 128 to 256 in xwax.c
    - Updated buffersize in scsettings.txt from 128 to 256
    Benefits:
    - Reduces audio interrupts by 50% (from every 1.33ms to 2.67ms @ 48kHz)
    - Provides more time for pitch calculations to settle
    - Reduces CPU overhead and jitter during scratching
    - Improves overall stability, especially during fast direction changes
    This larger buffer is optimal for the AudioInjector sound card on
    Raspberry Pi 2, balancing latency with stable scratch performance.
    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
    [xwax.c]
2025-11-09 Fix backward scratch velocity and eliminate flutter
    This commit addresses the root causes of flutter during backward
    scratching by fixing encoder processing and update rates.
    Critical fixes:
    1. REMOVED DOUBLE INVERSION BUG (sc_input.c:539)
    - Encoder was inverted permanently, then inverted again by jogReverse
    - This caused velocity calculation errors and flutter
    - Now jogReverse properly handles direction in process_rot()
    2. RE-ENABLED NOISE REJECTION (sc_input.c:629-633)
    - Noise rejection logic was commented out
    - Now filters erratic encoder jumps > 100 units
    - Requires 3 consecutive readings before accepting large changes
    3. INCREASED ARDUINO UPDATE RATE (arduino_nano.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
    [arduino_nano.ino, sc_input.c]
2025-11-09 Fix fast flutter by adjusting Arduino update rate to optimal 5ms
    The previous 2ms interval (500Hz) was too aggressive and caused
    timing jitter, resulting in very fast flutter.
    Problem Analysis:
    - Serial transmission @ 115200 baud: ~1.4ms per packet
    - analogRead(): ~0.1ms
    - capacitiveSensor(): ~0.5-1ms
    - Total loop time: ~2.5-3ms
    With 2ms interval, the loop couldn't complete in time, causing:
    - Irregular update timing (jitter)
    - Serial buffer issues
    - Erratic pitch updates = FAST FLUTTER
    Solution:
    - Changed interval from 2ms to 5ms (200Hz update rate)
    - Reduced capacitive sensor samples from 10 to 5
    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
    [arduino_nano.ino]
2025-11-09 Fix encoder direction to eliminate wowwly pitch oscillation
    The previous fix accidentally reversed the encoder direction, causing
    the system to fight against hand movements when touching the platter.
    - Removed permanent encoder inversion thinking it was a bug
    - This reversed the encoder direction from correct to backward
    - When user touched platter and moved forward:
    * System thought platter moved backward
    * Pitch calculation tried to catch up in wrong direction
    * Created oscillating/warbling "wowwly" pitch effect
    * Response was "very fast" due to fighting movements
    - Consolidated direction handling in ONE location (read_serial_data)
    - Normal mode: inver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
    [sc_input.c]
2025-11-09 Restore original encoder inversion logic
    The previous "fix" for double-inversion was incorrect and broke
    encoder tracking completely. The original inversion logic was
    correct for this hardware configuration.
    Restored behavior:
    - Line 539: encoder_value = 4096 - encoder_value (ALWAYS)
    - process_rot(): if (jogReverse) invert again
    This is the correct behavior - the hardware encoder direction
    requires inversion in normal mode, and double-inversion for
    reverse mode (which effectively reverses the direction).
    The flutter issue will be addressed by the OTHER fixes:
    - Pitch parameters (target_pitch, clamp_pitch, skip_pitch, pitch_mixer)
    - Buffer size increase (128->256)
    - Noise rejection re-enab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
    [sc_input.c]
2025-11-11 Add 3-slot preset system for saving/loading configurations
    Implemented a comprehensive preset system that allows saving and loading
    complete system states including deck files and all settings.
    Features:
    - 3 preset slots for saving/loading configurations
    - Menu accessible via Main Menu -> Presets Menu
    - Save current state (both deck files + all settings)
    - Load any preset from menu
    - Auto-load last used preset at startup
    - Preset files stored in /home/no3z/.scratchtj/presets/
    What gets saved in each preset:
    - Deck 0 & 1: current folder and file paths
    - Integer settings: buffersize, platterspeed, slippiness, brakespeed,
    faderopenpoint, faderclosepoint, jogReverse, cutbeats, pitchrange
    - F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
    [main_menu.c, preset_menu.c, xwax.c]
2026-03-04 Fix wurbly scratching caused by non-uniform encoder mapping and over-aggressive blip filter
    Two root causes identified for unstable/wurbly scratch sound when using a
    2400 CPR rotary encoder in place of the AS5601 magnetic sensor:
    1. arduino_nano: Non-uniform angle mapping due to integer truncation
    The formula `(encoderValue % CPR) * 4096 / CPR` with CPR=2400 produces
    non-uniform step sizes (alternating +1 and +2 mapped units per encoder tick)
    because 4096/2400 = 1.707 is not a whole number. This causes the audio
    engine to see alternating fast/slow position jumps, creating pitch wobble.
    Fixed by using floating-point round() instead of integer truncation.
    Also normalises neg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
    [arduino_nano.ino, sc_input.c]
2026-03-04 Fix encoder CPR to 4096, add blipthreshold and pitch_filter to config menu
    1. arduino_nano: Fix CPR from 2400 to 4096. The encoder is 1024 PPR with
    4x quadrature decoding (CHANGE interrupts on both A and B pins), which
    gives 4096 counts per revolution. With CPR=4096 the angle mapping becomes
    a perfect 1:1 identity (4096/4096=1), completely eliminating the non-uniform
    step sizes that were the primary cause of wurbly scratching sound.
    2. xwax.c + sc_input.c: Make blip filter threshold configurable via the
    "blipthreshold" shared variable (default 400, range 50-2048, step 50).
    Accessible from Config Menu → Global Settings on the LCD. This replaces
    the hardcoded value so u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
    [arduino_nano.ino, player.c, sc_input.c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]
2026-03-04 Fix menu rotary encoder missing most turns
    The rotary_encoder_moved() function had three issues causing it to miss
    most encoder clicks:
    1. Only detected 2 of 4 valid quadrature transitions (only 11→10 and
    11→01, ignoring all transitions through state 00). Most turns were
    simply invisible to the code.
    2. Debounce was applied before reading state — if called during the
    debounce window, it returned 0 without updating lastEncoded, so by
    the time debounce expired the transition was already lost.
    3. Polling thread ran at 20Hz (usleep 50ms) — too slow to reliably
    catch fast encoder clicks.
    Replaced with a full quadrature state transition table that tracks all
    4 states cor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
    [lcd_menu.c]
2026-03-04 Remove unused lastTurnTime and ROTARY_DEBOUNCE_DELAY from lcd_menu.c
    These were left over from the old debounce-based encoder reading logic
    replaced in a120ad9. The new quadrature state table approach uses an
    accumulator for debouncing instead of a time-based delay, so these
    variables are no longer needed. Fixes -Wunused-variable warning.
    [lcd_menu.c]
2026-03-04 Optimize for 600 PPR encoder: use native 2400 CPR, eliminate lossy 4096 mapping
    Arduino now sends raw encoder position (0-2399) instead of mapping to 4096,
    removing integer truncation that caused alternating +1/+2 step errors.
    All sc_input.c boundaries use ENCODER_CPR constant instead of hardcoded 4096.
    Adjusted platterspeed to 1800 and blipthreshold to 250 for 2400 CPR scale.
    [arduino_nano.ino, sc_input.c, xwax.c]
2026-03-04 Major serial + performance optimizations: binary protocol, 500kbaud, cap hysteresis, variable caching
    1. Binary serial protocol: Replace ASCII text parsing with 8-byte binary
    packets (sync + 6 data bytes + XOR checksum). Reduces transmission
    time from ~1.3ms to ~0.13ms per packet at 500kbaud.
    2. Baudrate 500000: 4.3x faster than 115200, minimizing serial latency.
    3. Capacitive touch configurable + hysteresis: cap_threshold and
    cap_hysteresis are now shared variables adjustable from the LCD menu.
    Hysteresis prevents touch flicker that causes audio clicks.
    4. Position interpolation: Computes encoder velocity between serial
    updates for smoother motion tracking during fast scra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
    [arduino_nano.ino, player.c, sc_input.c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]
2026-03-04 Add Presets submenu to Config menu with save/load/reset
    Wire preset system into Config menu (Config → Presets → Save/Load/Reset).
    Save and Load support 5 slots with date metadata shown on LCD.
    Reset restores scsettings integers and float variables to defaults.
    Also adds preset_menu.o to Makefile and updates controller_menu to
    accept decks array for preset access.
    [controller_menu.c, deck_menu.c, info_menu.c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]
2026-03-04 Rewrite README with full project documentation
    Merges content from master (2-button add-on, alicomponents photo,
    Tinkercad links with share codes, pitch mode) with all main branch
    features: binary serial protocol, 500kbaud, encoder optimizations,
    preset system, runtime-tunable parameters table, capacitive hysteresis,
    cached variables, menu structure, build instructions, and architecture
    diagram.
2026-03-04 Update README: remove MIDI refs, add cue/recording docs, track missing images
    - Remove all MIDI references (project does not support MIDI)
    - Add Two-Button Cue System section documenting Enter/Back cue controls
    - Add Live Input Recording section documenting ALSA capture feature
    - Add recording.c, cues.c, deck_menu.c to source files table
    - Track docs/2buttons.png and docs/alicomponents.png (were on master only)
2026-03-04 Add comprehensive build guide with step-by-step wiring and assembly instructions
    Full beginner-friendly guide covering:
    - Complete bill of materials with prices
    - Arduino wiring: encoder (D2/D3), fader (A5), capacitive touch (D10/D12/1.2kΩ)
    - Raspberry Pi wiring: serial (GPIO 14/15), LCD I2C (GPIO 2/3), menu encoder
    (GPIO 23/24/25), buttons (GPIO 17/27)
    - Capacitive touch trick explained (wire through encoder shaft to HDD platter)
    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
2026-03-04 Rename all photos to match their actual content
    Every photo was analyzed and renamed to accurately describe what it shows:
    - enclosure_and_controls → breadboard_prototyping (workbench with breadboard, not enclosure)
    - encoder_closeup → dj_fader_closeup (shows DJ fader, not encoder)
    - IMG_3892 → assembled_front_view (finished unit from front)
    - IMG_3893 → assembled_back_view (finished unit from back)
    - initial_build_setup → enclosure_side_view (side view of enclosure with platter)
    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
2026-03-04 Distribute all photos inline throughout build guide
    Move photos from generic "Build Photos" dump to their relevant sections:
    - Encoder closeup → encoder wiring section (2.1)
    - DJ fader closeup → fader wiring section (2.2) — previously unused
    - Capacitive resistor → cap sensing section (2.3)
    - Breadboard prototyping → Pi setup intro (Step 3) — previously unused
    - LCD + encoder breadboard → LCD wiring section (3.5)
    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
2026-03-04 Move enclosure/platter photos to capacitive touch section
    Enclosure side view and top-down view show the platter and wiring
    which is most relevant in the capacitive sensing section. Removed
    the resistor closeup photo from that section per feedback.
2026-03-04 Revise build guide for clarity and add back view image
    Removed unnecessary phrasing and added an image of the assembled back view.
2026-03-04 Add Recent Improvements section to README
    Document all major fixes and optimizations:
    - Scratch feel: native 2400 CPR, SC1000-calibrated defaults, dual pitch
    filter, slipmat overshoot clamping, position interpolation, blip tuning
    - Serial: binary protocol at 500kbaud, handshake, watchdog + DTR reset
    - Controls: full quadrature menu encoder, 2-button cue, cap hysteresis
    - Performance: cached variable pointers, 5-slot presets, default tracking
2026-03-30 Add enclosure design docs: SCAD mount, CadQuery turntable, design notes
    [parametric_encoder_mount.scad]
2026-03-30 Cue system improvements and display driver additions
    - Cue set fires immediately on long-press threshold (no waiting for release)
    - Cue trigger (short press) seeks audio position and resyncs platter
    - Per-cue colored squares: CUE1 red, CUE2 green, CUE3 yellow, CUE4 blue
    - Cue trigger flashes yellow for 300ms then reverts to cue color
    - Cue banner shows "CUE N SET" in medium font on set
    - Pin remap on Pi side: A0->CUE1, A3->CUE2, A1->CUE3, A2->CUE4
    - Add GPIO direct driver (mmap-based, replaces wiringPi)
    - Add ST7789 TFT display driver and SSD1306 OLED driver
    - Ghost needle uses absolute audio position (no angleOffset)
    [gpio_direct.c, main_menu.c]
2026-03-30 Add fader deadzone for clean cut at extremes
    2% deadzone at both ends of crossfader ensures volume
    hard-cuts to zero when fully closed to either side.
2026-03-31 ScratchTJ MK2: TFT display, magnetic encoder, new enclosure, full documentation
    Major hardware upgrade from MK1 (tagged as mk1):
    - ST7789 240x240 color TFT replacing 1602 LCD
    - MT6701 14-bit magnetic encoder replacing optical rotary
    - Slip ring capacitive touch system
    - Direct GPIO register access (no wiringPi dependency)
    - Full graphical menu system with color themes
    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
    [AudioInjector_Case_print.stl, base_shell.stl, bottom_cover.stl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]
2026-03-31 SC1000 parameter matching: target_pitch=40, buffer=256, no input sleep, fader curve graph, fader_sharp parameter
    - Match SC1000 defaults: target_pitch=40, pitch_filter=0.1, platterspeed=9100
    - Buffer size 256 with proper ALSA period size setting
    - Remove usleep from input loop for ~2-5kHz encoder polling (matches SC1000)
    - Add fader_sharp parameter (instant fader by default)
    - Add fader curve visualization on TFT when editing fader params
    - Fix ALSA period_size_near for small buffer support
    [controller_menu.c, player.c, sc_input.c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]
2026-03-31 Arduino firmware: decouple fader from cap sensor timing
    Fader+buttons read every loop (~0.2ms), cap sensor every 5th loop (30 samples).
    Fader updates at ~5kHz instead of ~100Hz blocked by capacitiveSensor().
2026-04-01 File browser, recording, and UI improvements
    - Add visual file/folder browser to deck menu (replaces flat Load File actions)
    - Add Start/Stop to deck menu
    - Add fader history graph on home screen
    - Add recording input source selection and setup
    - LCD menu updates
    [deck_menu.c, lcd_menu.c, main_menu.c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]
2026-04-01 Update README and build guide for MK2 hardware
    Rewrite docs to reflect current architecture: MT6701 encoder on I2C,
    ST7789 TFT display, 7-byte serial protocol, 4 cue buttons. Remove old
    images, use docs/imageX.jpeg only. Add MK2 build video. Remove MIDI refs.
2026-04-01 Docs update, recording fix, WAV import improvements
    - Add MT6701 and ST7789 product images to build guide
    - Update INSTALLATION.md: required packages (ffmpeg, mpg123, sox),
    audio format guide, WAV conversion commands, new troubleshooting entries
    - Fix serial protocol docs (7 bytes, not 6), preset slots (5, not 3)
    - Fix recording bug: close peak meter ALSA handle before starting capture
    to prevent device-busy errors (deck_menu.c, recording.c, recording.h)
    - xwax-import: decode mono WAVs to stereo via ffmpeg instead of raw dd
    [deck_menu.c]
2026-04-03 Repo cleanup: reorganize tests, images, and rewrite docs
    - Move all test scripts/programs to hw_test/ with dedicated Makefile
    - Move images to docs/images/, remove old MK1 photos and legacy OBJ files
    - Rewrite README with proper SC1000 credit, MK2 content, correct 7-byte protocol
    - Rewrite BUILD_GUIDE with full system wiring diagram, GPIO pin map,
    capacitive touch circuit, per-component wiring tables, and validation steps
    - Distribute images contextually throughout docs instead of image walls
    [djsc.obj, tinker.obj]
2026-04-03 Docs: full menu tree, distributed videos/images, attributions
    - Document complete menu system from code (all deck, config, recording,
    preset, and info options with navigation controls)
    - Spread demo videos throughout README instead of grouped at top
    - Place menu/buttons video next to menu documentation
    - Add OpenSCAD encoder mount screenshot to build guide
    - Fix 4 cue buttons (Arduino A0-A3), not 2 GPIO buttons
    - Fix serial protocol to 7-byte MK2 format
    - Add build guide link at top of README
    - Add proper attributions (xwax, SC1000, AudioInjector)
2026-04-03 Docs: fix menu tree against actual code
    - Fix navigation: KB0 (GPIO 17) = select/enter, encoder push = back
    - Fix preset slots: 3 not 5, note preset menu not yet wired in
    - Expand home screen description to match code (platter viz, fader
    arc, ghost/physical needles, info column, cue flash)
    - Remove Volume from deck menu (not in menu items list)
    - Show dynamic main menu labels as they appear on screen
    - Add click-to-play labels on all video embeds
2026-04-04 UI overhaul: function modes, deck switching, recording simplification
    - Rotary button: faster debounce (30ms vs 100ms), long press (500ms) switches active deck
    - Function modes (CUE/SETTINGS) selectable from main menu
    - SETTINGS mode: btn1=pitch, btn2=platterspeed, btn3=start/stop, btn4=volume (gain up to 3.6x)
    - Hold button + rotate platter to adjust parameters with live overlay display
    - Active deck switching: platter, cue buttons, and home screen follow selected deck
    - Volume gain: separated from pitch-based volume, no scratch distortion
    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
2026-04-04 Update README: document function modes, deck switching, simplified recording
    - Document CUE and SETTINGS function modes with button assignments
    - Update navigation controls (long press = deck switch, no auto-return)
    - Update menu tree to reflect current state (simplified recording, no pitch/volume in deck menu)
    - Add SETTINGS mode parameter table with colors, ranges, and control method
2026-04-04 Switch to USB serial, add function modes and deck switching
    Replace GPIO UART (/dev/serial0) with USB serial (/dev/ttyUSB0) for
    Arduino communication — simpler wiring, no level shifter needed.
    Add settings/cue function modes with platter-based parameter adjustment,
    active deck switching, and updated menu system. Update all docs to
    reflect USB serial setup.
    [sc_input.c, xwax.c]
2026-04-04 Docs: fix menu tree, parameters, button roles, and serial references
    - Fix menu tree: Load File items shown at correct level (not nested
    under File Browser)
    - Fix parameter defaults table against actual code (platterspeed=9100,
    target_pitch=40, blipthreshold=400, pitch_filter=0.1, add fader_sharp
    and fhist_secs, remove nonexistent cap_threshold/cap_hysteresis)
    - Fix KB0 button role: select/confirm (not back)
    - Fix encoder push role: short=back, long=switch deck (not Pitch Mode)
    - Fix cue buttons: on Arduino A0-A3 (not MCP23017/Pi GPIO)
    - Remove remaining GPIO UART references from BUILD_GUIDE (section 9
    serial connection, wiring diagram, GPIO pin table)
    - Add function mode description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
2026-04-04 Add parametric Innofader Pro SC fader cassette (CadQuery)
    Adapter cassette that mounts to the stock 4-hole shell pattern and
    internally holds the Mini Innofader Pro SC on 2x M3 standoffs at
    65mm spacing. No base shell reprint needed.
2026-04-13 Fader and settings adjust overhaul
    - Tighten fader deadzone 2%/98% → 0.5%/99.5% to match Innofader Mini Pro
    (same cut zone as SC500 faderopenpoint=5/1023)
    - Enable USB serial low-latency flag (ASYNC_LOW_LATENCY) to bypass the
    16ms kernel tty buffer, reducing encoder/button input latency
    - Raise volume cap 3.6 → 8.0 for louder deck output
    - Finer pitch step 0.005 → 0.001 (musical tuning granularity)
    - Add platter-speed-based acceleration (×1 slow, up to ×10 fast) to all
    settings adjustments for intuitive coarse/fine control
    - Reassign btn 2 in SETTINGS mode to fader_pitch bend (±8% turntable
    range) for beatmatching; removed start/stop on btn 2 press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
    [sc_input.c]
2026-04-13 Soft-clip limiter and UI for new bend / extended volume
    - Replace hard digital clip in build_pcm with tanh-based soft saturation
    for warm analog-style overdrive at higher gains
    - Raise internal target_volume ceiling 4.0 → 8.0 to make the new x8 cap
    in setVolume actually usable (soft_clip handles the saturation)
    - Update settings overlay UI: btn 2 label now "BEND" (was START/STOP),
    shows percentage ±X.X% with bar centered on ±8% range
    - Volume bar now scales 0–8x (was 0–3.6x)
    [main_menu.c, player.c]
2026-11-11 Tighter platter tracking, faster fader, persistent mixer, FTP access
    Platter
    - Measure platter velocity from timestamped encoder samples
    (platter.c) and feed it forward into the player pitch; the SC1000
    position loop now only trims the residual error. Replaying a recorded
    scratch, mean position error drops from 153 ms to 2 ms. vel_ff = 0
    restores the original SC1000 tracking.
    - motion_touch: optionally treat a moving platter as touched, so the
    instrument is playable without a working capacitive touch sensor.
    - Audio and input threads run under SCHED_FIFO (80 / 60).
    - Read the MT6701 in one combined I2C transaction; skip failed reads
    instead of reprocessing a stale angle; release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
2026-11-11 Config menu: Restart (rescan files) and Reboot Pi
    Restart re-executes xwax in place so it reads the beats and samples
    folders again, e.g. after copying files over FTP; SIGUSR1 triggers the
    same. Both options ask for confirmation and save config and cues first.
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

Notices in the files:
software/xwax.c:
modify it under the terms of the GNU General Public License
